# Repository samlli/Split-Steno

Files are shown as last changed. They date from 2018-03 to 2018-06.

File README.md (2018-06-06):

# Split Stenographic Keyboard

**current working version: rev1.1**

Open source PCB design for a mirrored keyboard with the layout below:

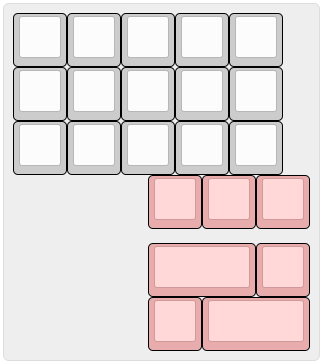
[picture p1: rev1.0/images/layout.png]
layout


**rev1.x Features:**

ATmega32u4 controller  
Mirrored Alps + MX compat  
3 x 1u / 2u + 1u bottom row layout support  
THT & SMD support  
<100x100mm square PCB size  
QMK firmware

**rev2.x Features:**

ATxmega controller  
nRF24L01+ wireless  
Per-key LED backlighting  
WS2812b underglow   
Wired & coin cell battery support  
Trackpoint support  
KeyPlus firmware

**rev3.x Features:**
Minimized PCB layout
Removed mirrored compat

## Build Guide

**required parts**

Quantities are for a single PCB, double required quantities if you build two halves!

- 1x Atxmega32a4u
- 17-18x MX / Alps switches
- 0-1x PCB mount stabilizer
- 1x PJ-320A TRRS jack
- 1x Hirose 5S8 USB Mini B
- 1x Fuse
- 4x 0.1uF Capacitors
- 1x 10uF Capacitor
- 2x 4.7k Resistor
- 1x Voltage Regulator (component name needed)

## Setup

Fancy K+ stuff goes here I guess

## Why?

**why is this keyboard a thing?**

Good question - I'm not quite sure to be honest... when you find out, let me know please

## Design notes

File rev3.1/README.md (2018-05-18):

# rev3.0

**Features:**

Integrated ATxmega controller  
SMD only  
No Diodes   
Wireless NRF

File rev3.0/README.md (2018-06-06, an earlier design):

# rev3.0

**Features:**

Minimized PCB footprint  
Lite version with core functionality only  
NRF and RGB moved to breakouts  
Routed GND with 0 vias

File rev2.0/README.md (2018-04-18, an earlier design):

# rev2.0

**WARNING: INCOMPLETE/ABANDONED**

Reason: big forehead, decided to scrap and proceed with 2.1

**Features:**

Integrated ATxmega controller  
SMD only  
No Diodes  
Reversible PCB

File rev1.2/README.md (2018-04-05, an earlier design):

# rev1.2

**WARNING: INCOMPLETE/ABANDONED**

**Features:**

Added LED backlighting

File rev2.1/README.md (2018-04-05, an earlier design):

# rev2.1

**Features:**

Integrated ATxmega controller  
SMD only  
No Diodes  
Reversible PCB  
Wireless NRF

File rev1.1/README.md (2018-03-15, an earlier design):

# rev1.1

**left half**

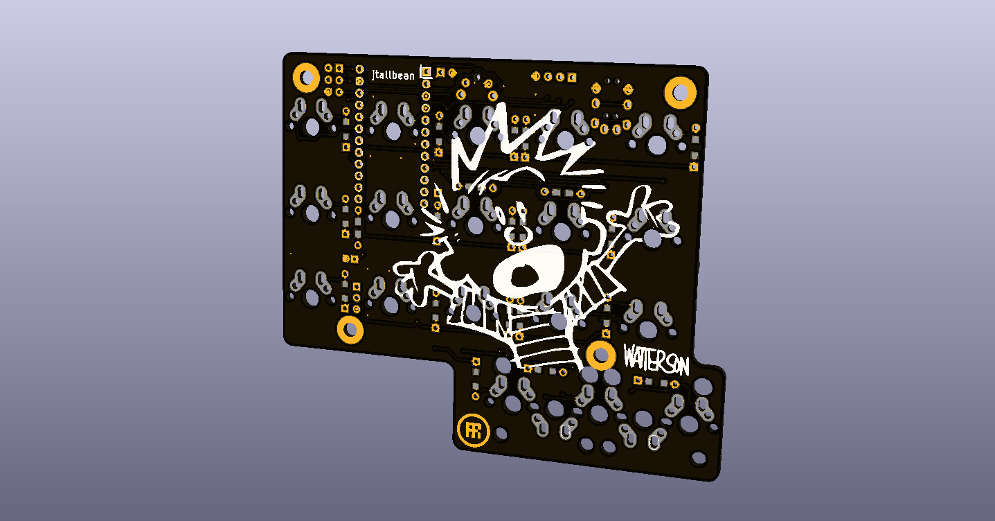
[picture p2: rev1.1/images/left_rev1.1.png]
left half


**right half**

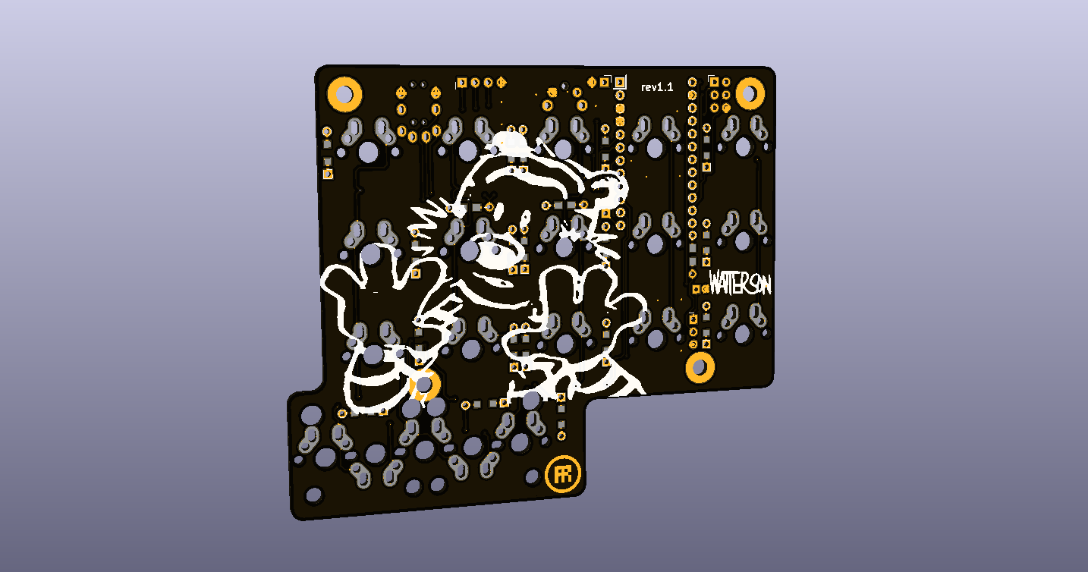
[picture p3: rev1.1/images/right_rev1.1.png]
right half


**Features:**

Pro Micro only  
Added mounting holes  
Added breakout for unused pins  
THT + SMD  
Added silkscreen design  
Cleaner routing

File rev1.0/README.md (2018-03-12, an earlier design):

# rev1.0

**left half**

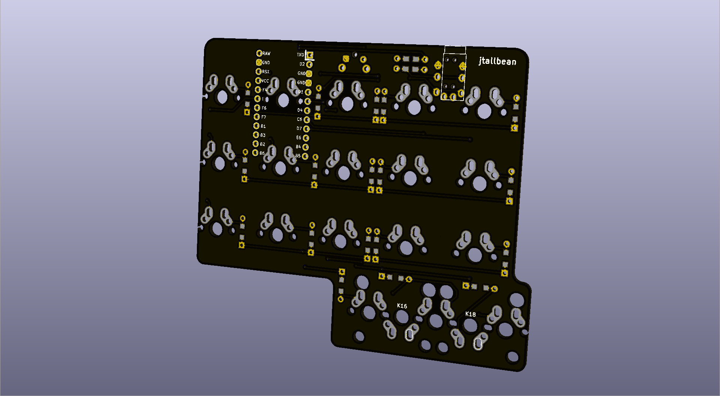
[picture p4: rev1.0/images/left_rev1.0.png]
left half


**right half**

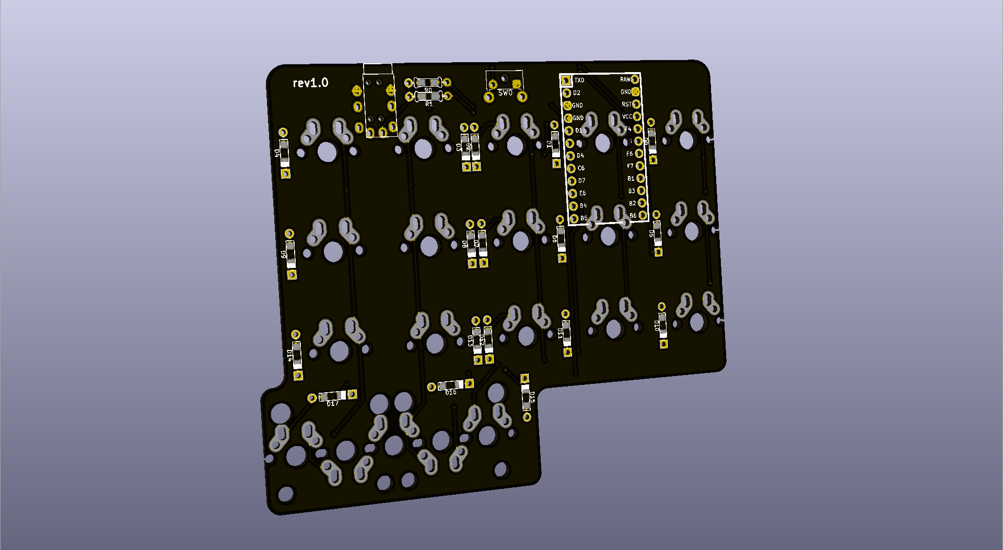
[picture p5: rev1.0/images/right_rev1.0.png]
right half


**Features:**

Pro Micro only  
NO mounting holes  
NO breakout for unused pins  
NO silkscreen design aside from name/rev  
First KiCad design - routing etc. not the cleanest

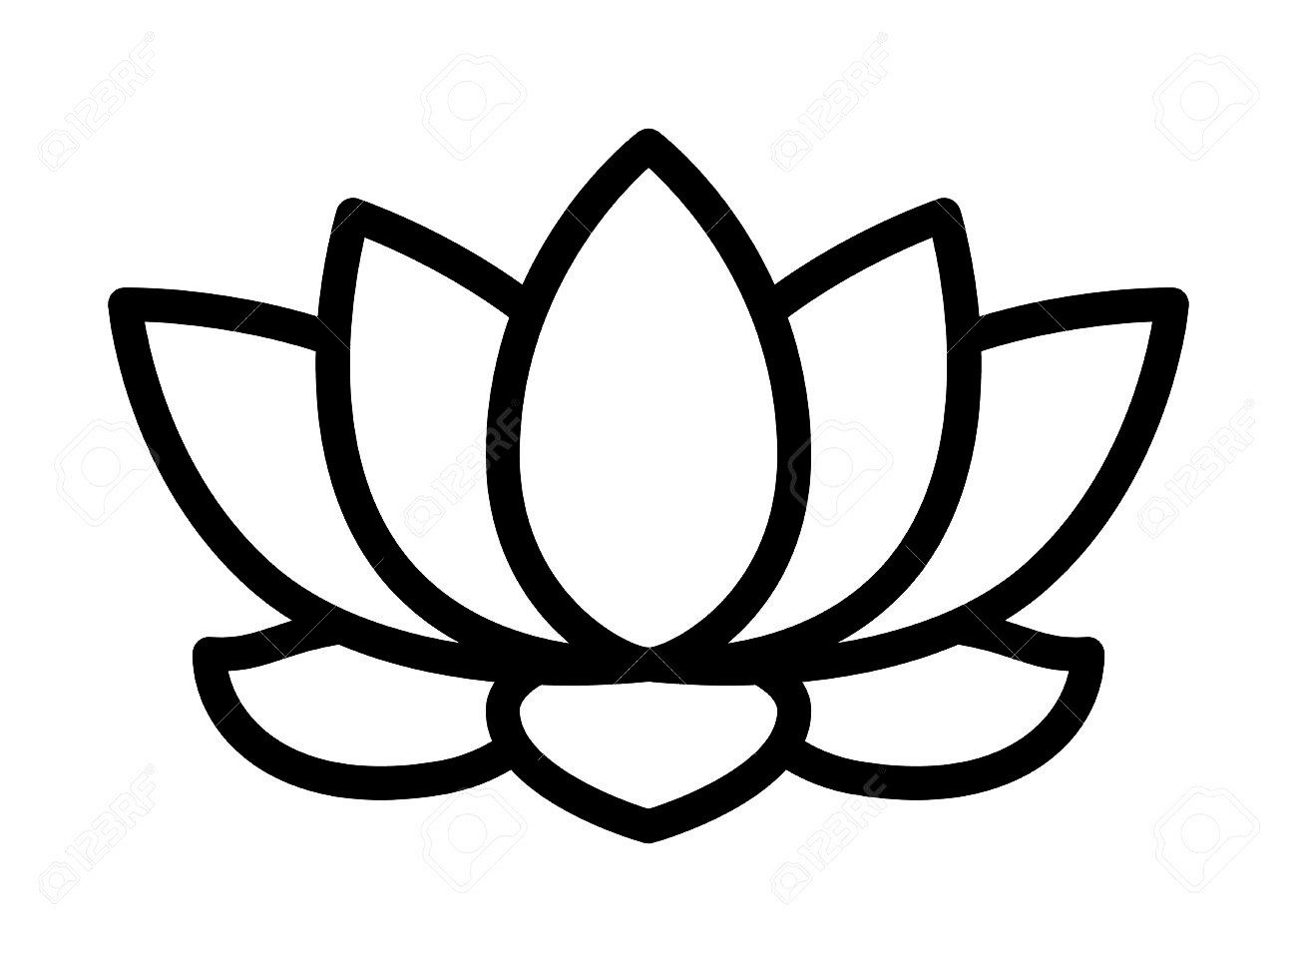
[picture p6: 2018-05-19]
rev3.1/images/lotus.png

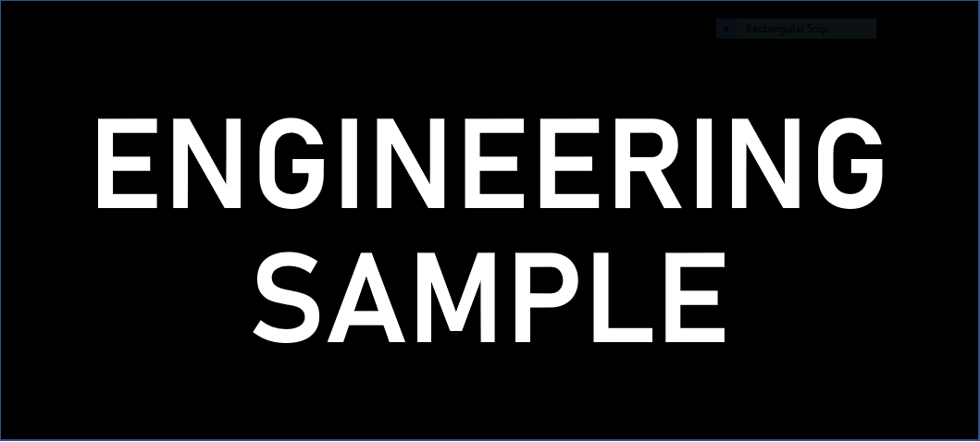
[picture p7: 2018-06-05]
rev3.1/images/engineering_sample.PNG

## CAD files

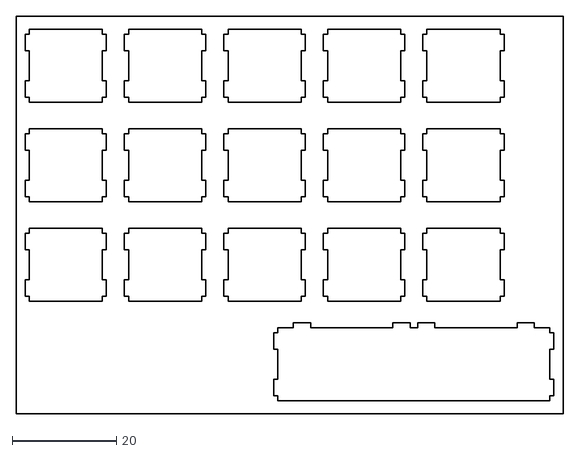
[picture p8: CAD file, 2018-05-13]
plate/split_steno_plate_universal_ch.dxf
104.8 x 76.2

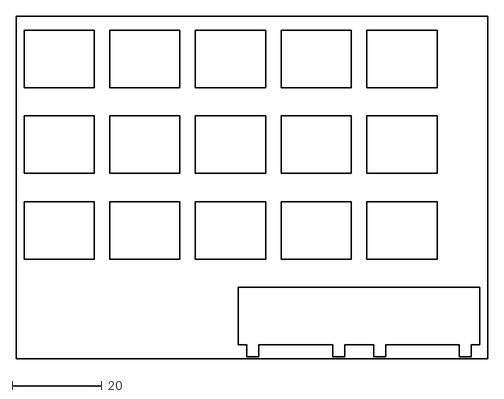
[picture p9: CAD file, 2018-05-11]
plate/split_steno_plate_universal_alps.dxf
104.8 x 76.2

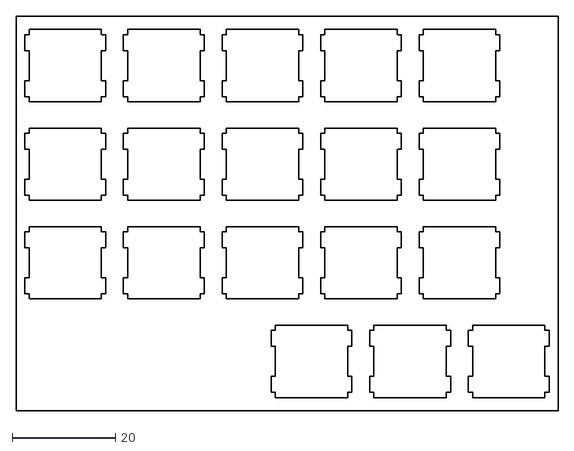
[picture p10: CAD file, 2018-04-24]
plate/split_steno_plate_1u_ch.dxf
104.8 x 76.2

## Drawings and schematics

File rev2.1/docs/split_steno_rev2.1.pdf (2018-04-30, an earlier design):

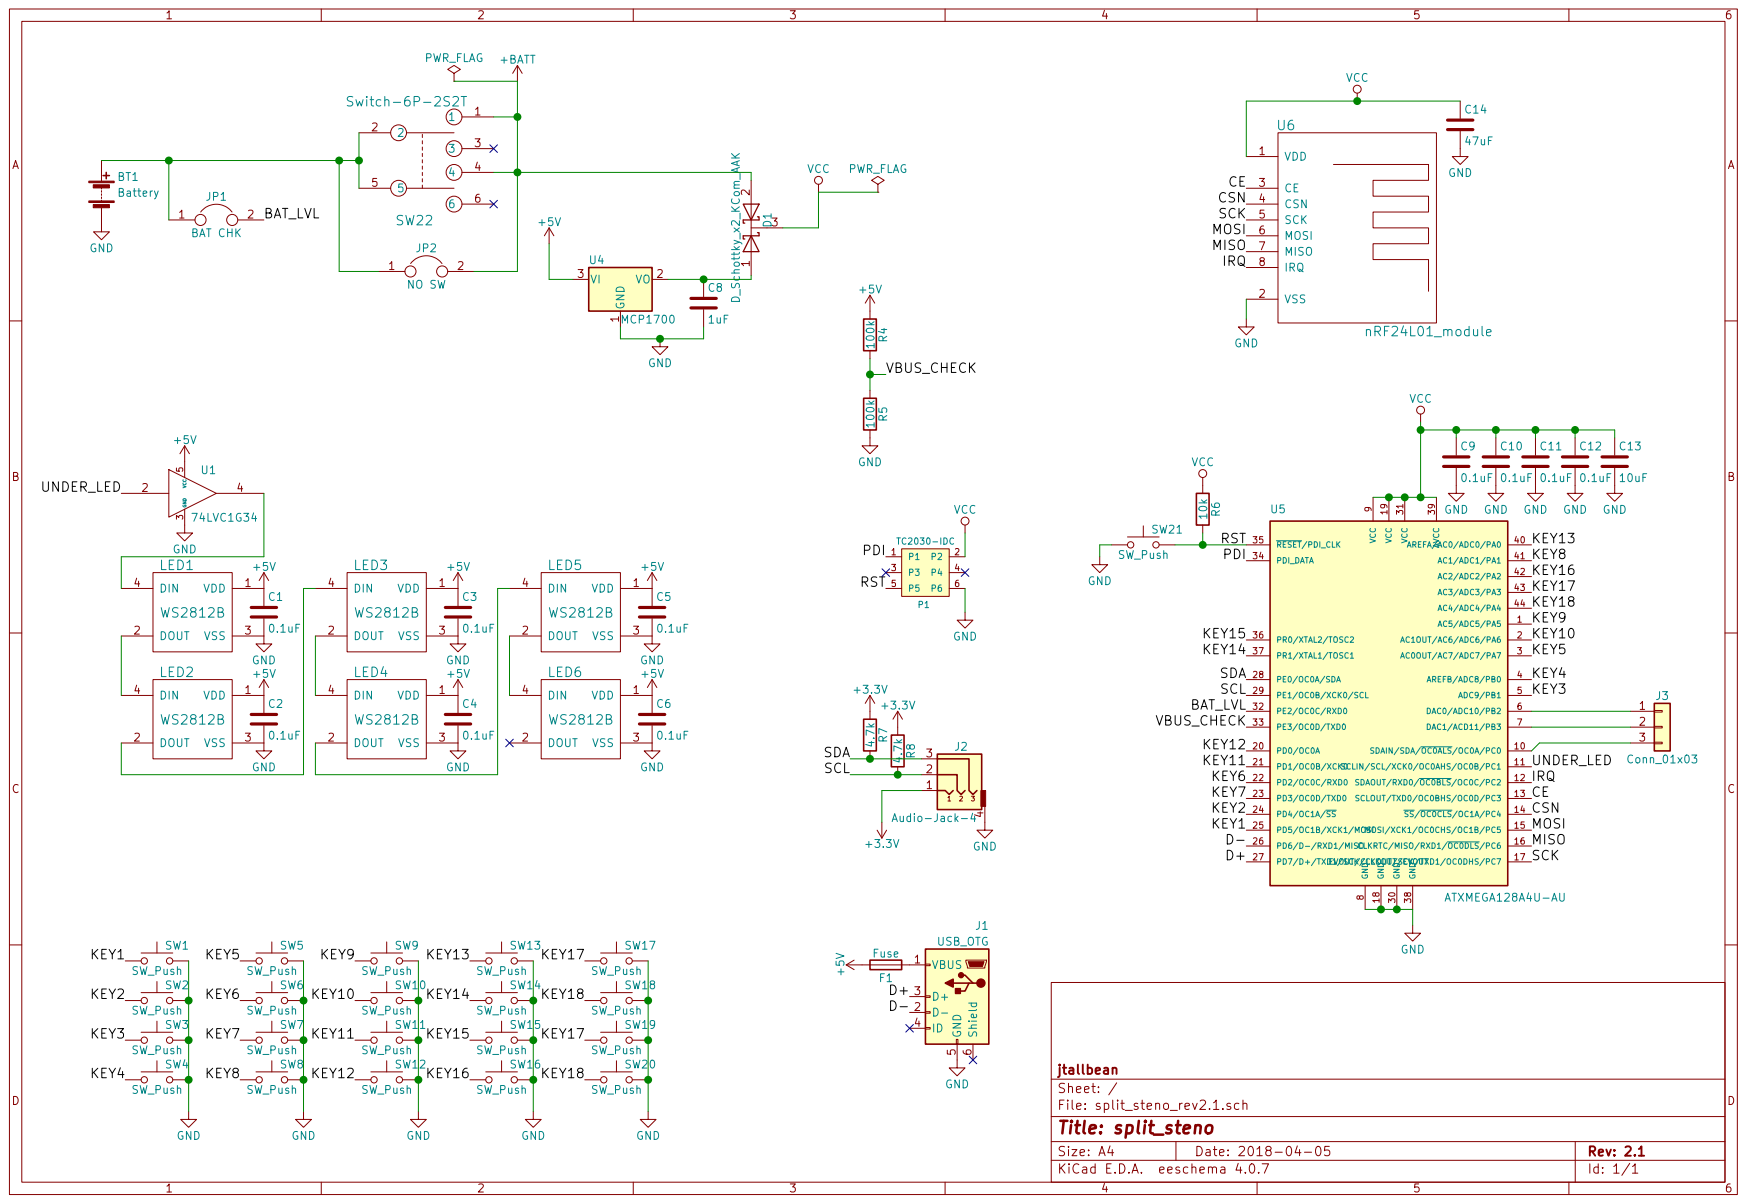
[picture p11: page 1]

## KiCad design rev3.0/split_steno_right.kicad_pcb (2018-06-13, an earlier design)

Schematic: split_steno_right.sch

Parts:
C1: 10uF; C_0603_HandSoldering
C2, C3, C4, C5: 0.1uF; C_0603_HandSoldering
F1: Fuse; Fuse_SMD1206_HandSoldering
J1: USB_B; USB_miniB_hirose_5S8
J2: Audio-Jack-4; TRRS-PJ-320A
J3, J5: Conn_02x04_Odd_Even; Pin_Header_Straight_2x04_Pitch2.54mm
J4: Conn_01x02; Pin_Header_Straight_1x02_Pitch2.54mm
P1: TC2030-IDC; TC2030-NL_SMALL_AND_IDC_PDI
R1, R2: 4.7k; R_0603_HandSoldering
SW1, SW2, SW3, SW4, SW5, SW6, SW7, SW8, SW9, SW10, SW11, SW12, SW13, SW14, SW15, SW16, SW17, SW18: SW_Push; MX-1U-NoLED
SW19, SW20: SW_Push; MX-2U-NoLED
U1: MIC550X; SOT-23-5_HandSoldering
U2: ATXMEGA-A4U-EPAD; TQFP-44_10x10mm_Pitch0.8mm

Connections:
+5V: F1.1, U1.1 (VIN), U1.3 (EN)
/CE: J3.3, U2.12 (SDAOUT/RXD0/~OC0BLS~/OC0C/PC2)
/CSN: J3.4, U2.14 (~SS~/~OC0CLS~/OC1A/PC4)
/D+: J1.3 (D+), U2.27 (PD7/D+/TXD1/SCK)
/D-: J1.2 (D-), U2.26 (PD6/D-/RXD1/MISO)
/EXTRA1: J4.1, U2.37 (PR1/XTAL1/TOSC1)
/EXTRA2: J5.4, U2.40 (AREFA/AC0/ADC0/PA0)
/EXTRA3: J5.3, U2.41 (AC1/ADC1/PA1)
/EXTRA4: J5.6, U2.42 (AC2/ADC2/PA2)
/EXTRA5: J5.5, U2.43 (AC3/ADC3/PA3)
/EXTRA6: J5.8, U2.44 (AC4/ADC4/PA4)
/IRQ: J3.8, U2.13 (SCLOUT/TXD0/OC0BHS/OC0D/PC3)
/KEY1: SW1.1, U2.36 (PR0/XTAL2/TOSC2)
/KEY2: SW2.1, U2.33 (PE3/OC0D/TXD0)
/KEY3: SW3.1, U2.25 (PD5/OC1B/XCK1/MOSI)
/KEY4: SW4.1, U2.24 (PD4/OC1A/~SS~)
/KEY5: SW5.1, U2.22 (PD2/OC0C/RXD0)
/KEY6: SW6.1, U2.2 (AC1OUT/AC6/ADC6/PA6)
/KEY7: SW7.1, U2.32 (PE2/OC0C/RXD0)
/KEY8: SW8.1, U2.20 (PD0/OC0A)
/KEY9: SW9.1, U2.23 (PD3/OC0D/TXD0)
/KEY10: SW10.1, U2.21 (PD1/OC0B/XCK0)
/KEY11: SW11.1, U2.1 (AC5/ADC5/PA5)
/KEY12: SW12.1, U2.3 (AC0OUT/AC7/ADC7/PA7)
/KEY13: SW13.1, U2.6 (DAC0/ADC10/PB2)
/KEY14: SW14.1, U2.10 (SDAIN/SDA/~OC0ALS~/OC0A/PC0)
/KEY15: SW15.1, U2.11 (SCLIN/SCL/XCK0/OC0AHS/OC0B/PC1)
/KEY16: SW16.1, SW19.1, U2.4 (AREFB/ADC8/PB0)
/KEY17: SW17.1, SW20.1, U2.5 (ADC9/PB1)
/KEY18: SW18.1, U2.7 (DAC1/ACD11/PB3)
/MISO: J3.7, U2.16 (CLKRTC/MISO/RXD1/~OC0DLS~/PC6)
/MOSI: J3.6, U2.15 (MOSI/XCK1/OC0CHS/OC1B/PC5)
/PDI: P1.1, U2.34 (PDI_DATA)
/RST: P1.5, U2.35 (~RESET~/PDI_CLK)
/SCK: J3.5, U2.17 (CLKOUT/SCK/TXD1/OC0DHS/PC7)
/SCL: J2.2, R1.1, U2.29 (PE1/OC0B/XCK0/SCL)
/SDA: J2.3, R2.1, U2.28 (PE0/OC0A/SDA)
GND: C1.2, C2.2, C3.2, C4.2, C5.2, J1.4 (GND), J1.5 (Shield), J1.6, J2.4, J3.1, J4.2, J5.1, P1.6, SW1.2, SW2.2, SW3.2, SW4.2, SW5.2, SW6.2, SW7.2, SW8.2, SW9.2, SW10.2, SW11.2, SW12.2, SW13.2, SW14.2, SW15.2, SW16.2, SW17.2, SW18.2, SW19.2, SW20.2, U1.2 (GND), U2.8 (GND), U2.18 (GND), U2.30 (GND), U2.38 (GND), U2.45 (EPAD)
unnamed: F1.2, J1.1 (VBUS)
VCC: C1.1, C2.1, C3.1, C4.1, C5.1, J2.1, J3.2, J5.2, P1.2, R1.2, R2.2, U1.5 (VOUT), U2.9 (VCC), U2.19 (VCC), U2.31 (VCC), U2.39 (AVCC)

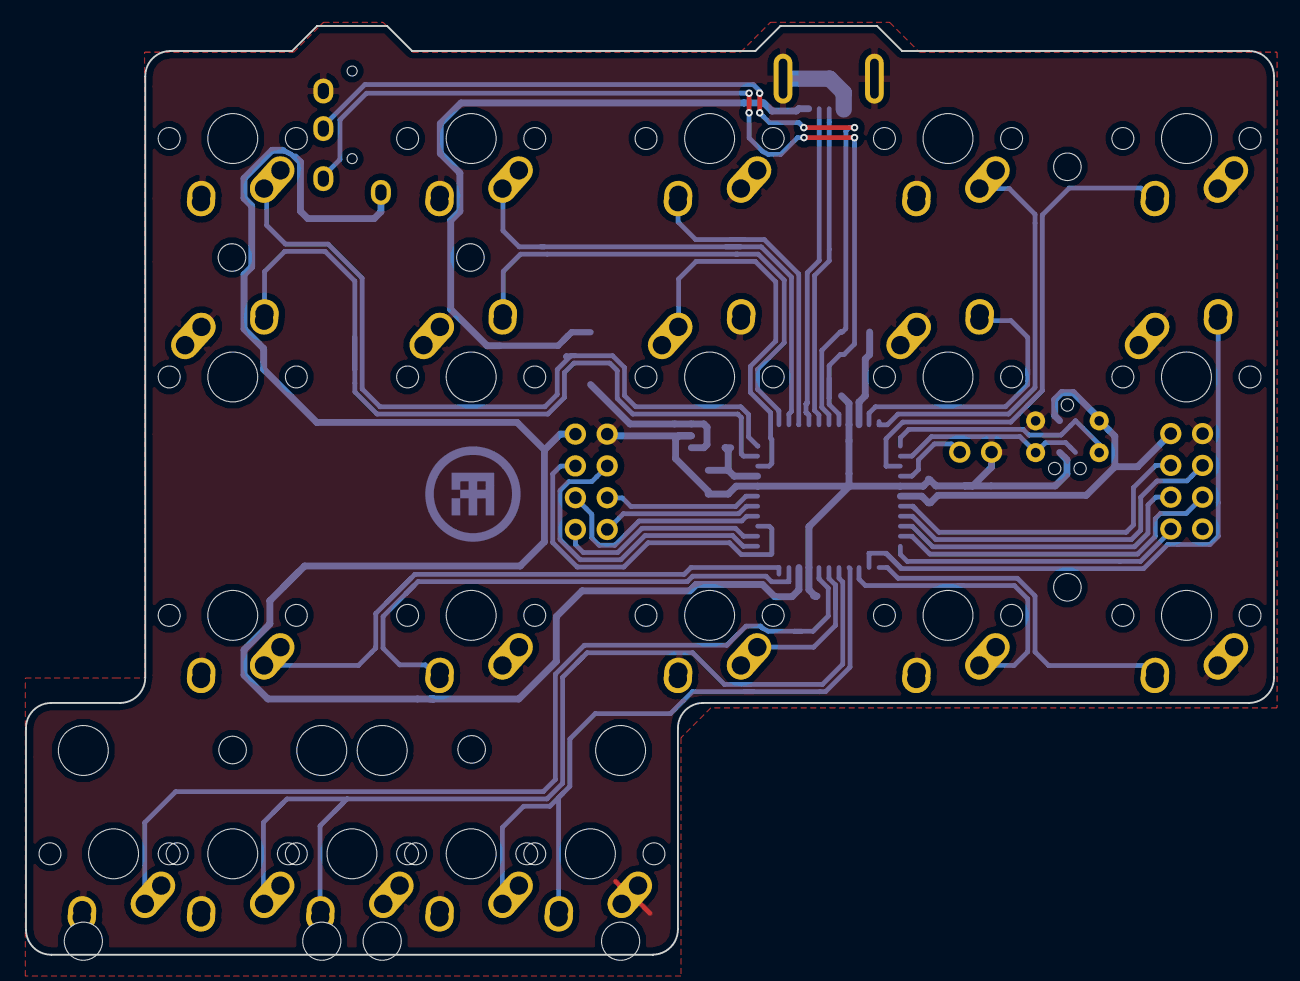
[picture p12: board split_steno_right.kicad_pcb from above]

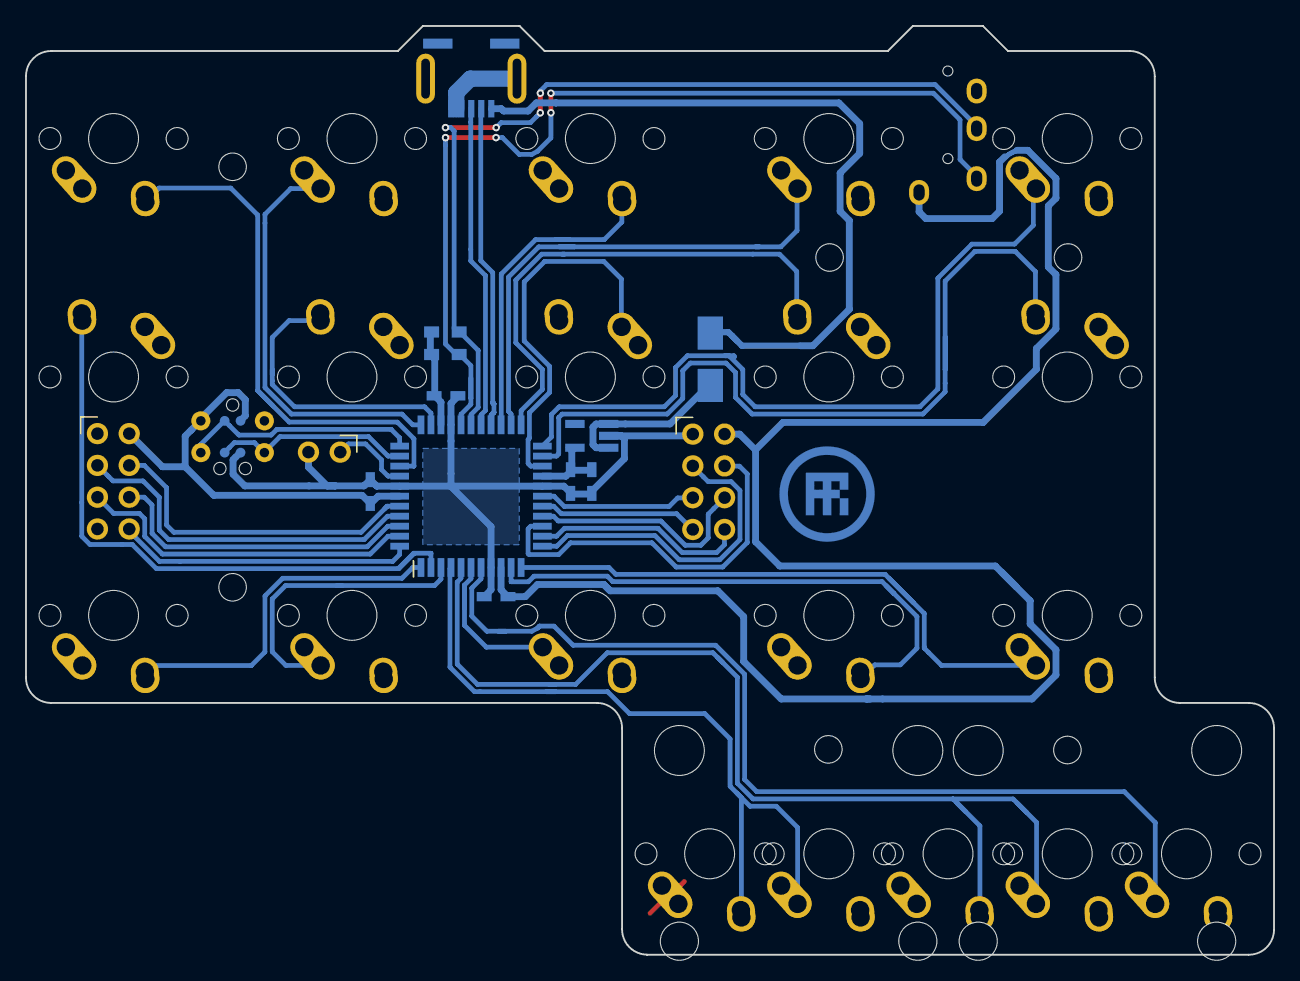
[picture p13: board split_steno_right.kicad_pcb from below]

Board: 2 copper layers, 99.7 x 74.2 mm, 42 parts (16 on the bottom side), 40 nets.

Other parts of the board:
M2, M2#2, M2#3, M2#4, M2#5, M2#6: MountingHole_2.2mm_M2

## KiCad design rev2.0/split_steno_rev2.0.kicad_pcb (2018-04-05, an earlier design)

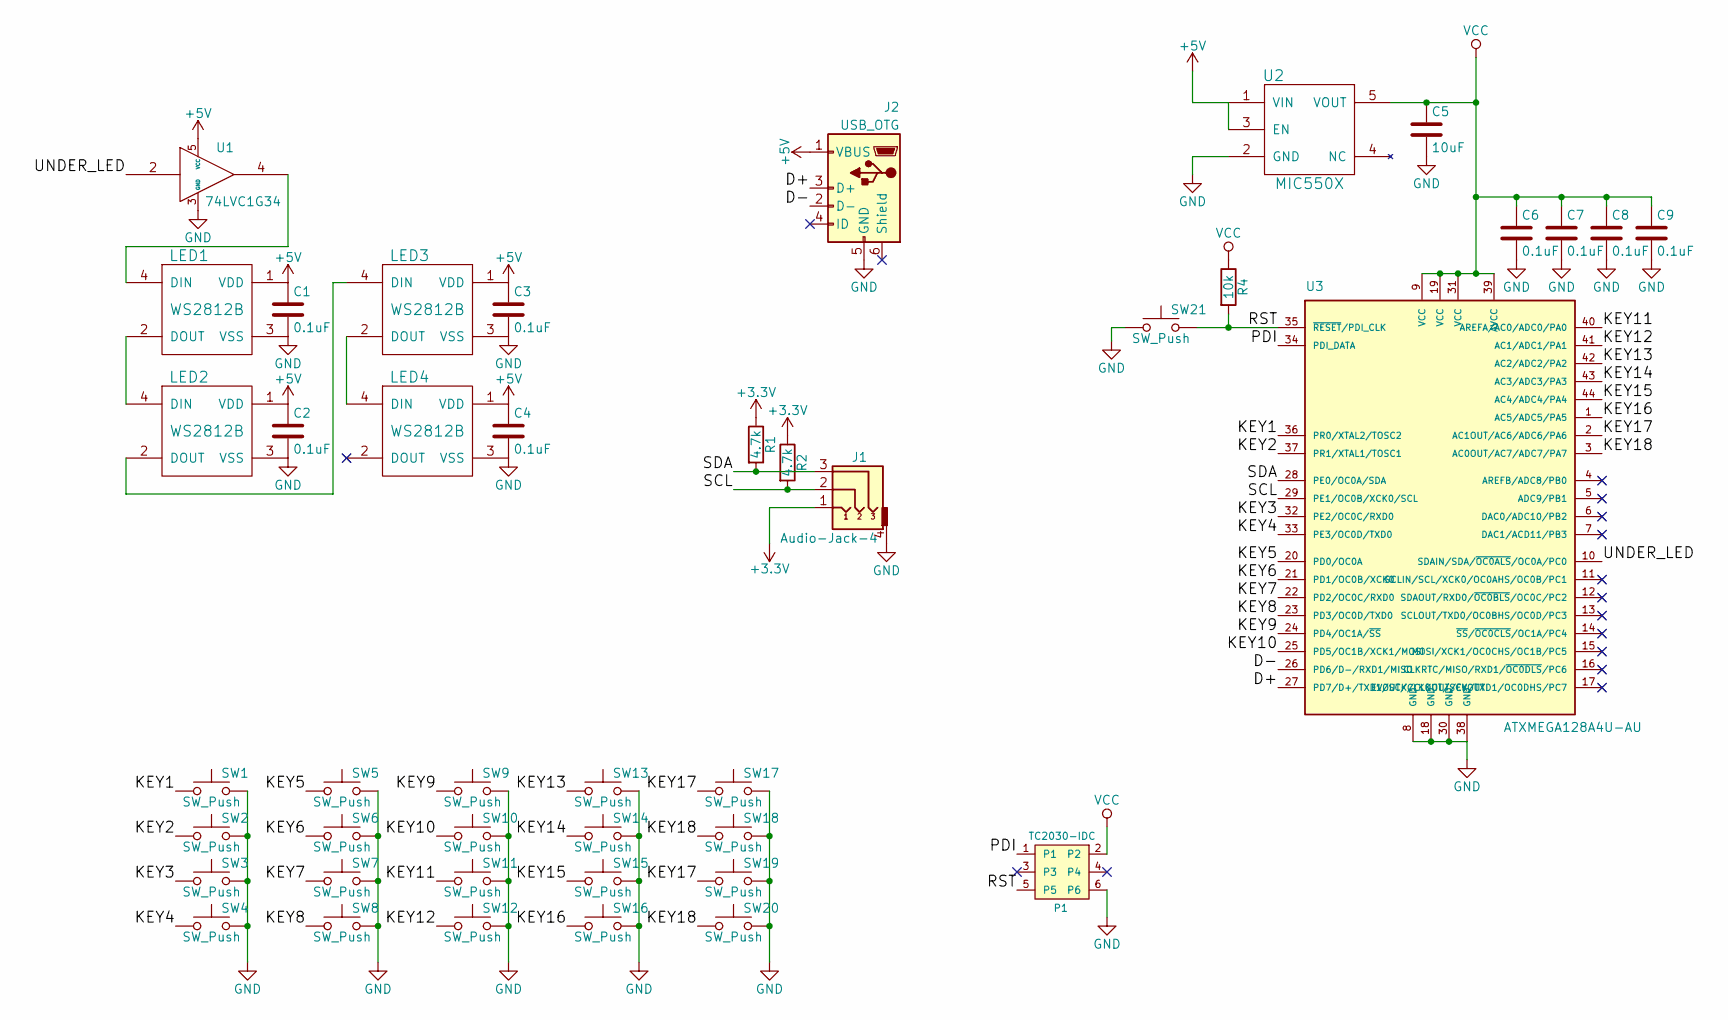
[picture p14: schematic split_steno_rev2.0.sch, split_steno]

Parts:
C1, C2, C3, C4, C6, C7, C8, C9: 0.1uF; C_0603_HandSoldering
C5: 10uF; C_0603_HandSoldering
J1: Audio-Jack-4; TRRS-PJ-320A
J2: USB_OTG; USB_miniB
LED1, LED2, LED3, LED4: WS2812B
P1: TC2030-IDC; Tag-Connect_TC2030-IDC-NL
R1, R2: 4.7k; R_0603_HandSoldering
R4: 10k; R_0603_HandSoldering
SW1, SW2, SW3, SW4, SW5, SW6, SW7, SW8, SW9, SW10, SW11, SW12, SW13, SW14, SW15, SW16, SW17, SW18: SW_Push; Hybrid_PCB_100H_Dual_hole
SW19, SW20: SW_Push; Hybrid_PCB_200H-dual-nosilk
SW21: SW_Push; SwitchPush_C&K_MultiFoot_RS-187R05A2-DS_And_PTS645_SMT
U1: 74LVC1G34; SOT-353_SC-70-5_Handsoldering
U2: MIC550X; SOT-23-5_HandSoldering
U3: ATXMEGA128A4U-AU; TQFP-44_10x10mm_Pitch0.8mm

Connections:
+3V3: J1.1, R1.1, R2.1
+5V: C1.1, C2.1, C3.1, C4.1, J2.1 (VBUS), LED1.1 (VDD), LED2.1 (VDD), LED3.1 (VDD), LED4.1 (VDD), U1.5 (VCC), U2.1 (VIN), U2.3 (EN)
/D+: J2.3 (D+), U3.27 (PD7/D+/TXD1/SCK/CLKOUT/EVOUT)
/D-: J2.2 (D-), U3.26 (PD6/D-/RXD1/MISO)
/KEY1: SW1.1, U3.36 (PR0/XTAL2/TOSC2)
/KEY2: SW2.1, U3.37 (PR1/XTAL1/TOSC1)
/KEY3: SW3.1, U3.32 (PE2/OC0C/RXD0)
/KEY4: SW4.1, U3.33 (PE3/OC0D/TXD0)
/KEY5: SW5.1, U3.20 (PD0/OC0A)
/KEY6: SW6.1, U3.21 (PD1/OC0B/XCK0)
/KEY7: SW7.1, U3.22 (PD2/OC0C/RXD0)
/KEY8: SW8.1, U3.23 (PD3/OC0D/TXD0)
/KEY9: SW9.1, U3.24 (PD4/OC1A/~SS~)
/KEY10: SW10.1, U3.25 (PD5/OC1B/XCK1/MOSI)
/KEY11: SW11.1, U3.40 (AREFA/AC0/ADC0/PA0)
/KEY12: SW12.1, U3.41 (AC1/ADC1/PA1)
/KEY13: SW13.1, U3.42 (AC2/ADC2/PA2)
/KEY14: SW14.1, U3.43 (AC3/ADC3/PA3)
/KEY15: SW15.1, U3.44 (AC4/ADC4/PA4)
/KEY16: SW16.1, U3.1 (AC5/ADC5/PA5)
/KEY17: SW17.1, SW19.1, U3.2 (AC1OUT/AC6/ADC6/PA6)
/KEY18: SW18.1, SW20.1, U3.3 (AC0OUT/AC7/ADC7/PA7)
/PDI: P1.1, U3.34 (PDI_DATA)
/RST: P1.5, R4.2, SW21.2, U3.35 (~RESET~/PDI_CLK)
/SCL: J1.2, R2.2, U3.29 (PE1/OC0B/XCK0/SCL)
/SDA: J1.3, R1.2, U3.28 (PE0/OC0A/SDA)
/UNDER_LED: U1.2, U3.10 (SDAIN/SDA/~OC0ALS~/OC0A/PC0)
GND: C1.2, C2.2, C3.2, C4.2, C5.2, C6.2, C7.2, C8.2, C9.2, J1.4, J2.5 (GND), LED1.3 (VSS), LED2.3 (VSS), LED3.3 (VSS), LED4.3 (VSS), P1.6, SW1.2, SW2.2, SW3.2, SW4.2, SW5.2, SW6.2, SW7.2, SW8.2, SW9.2, SW10.2, SW11.2, SW12.2, SW13.2, SW14.2, SW15.2, SW16.2, SW17.2, SW18.2, SW19.2, SW20.2, SW21.1, U1.3 (GND), U2.2 (GND), U3.8 (GND), U3.18 (GND), U3.30 (GND), U3.38 (GND)
unnamed: LED1.2 (DOUT), LED2.4 (DIN)
unnamed: LED1.4 (DIN), U1.4
unnamed: LED2.2 (DOUT), LED3.4 (DIN)
unnamed: LED3.2 (DOUT), LED4.4 (DIN)
VCC: C5.1, C6.1, C7.1, C8.1, C9.1, P1.2, R4.1, U2.5 (VOUT), U3.9 (VCC), U3.19 (VCC), U3.31 (VCC), U3.39 (AVCC)

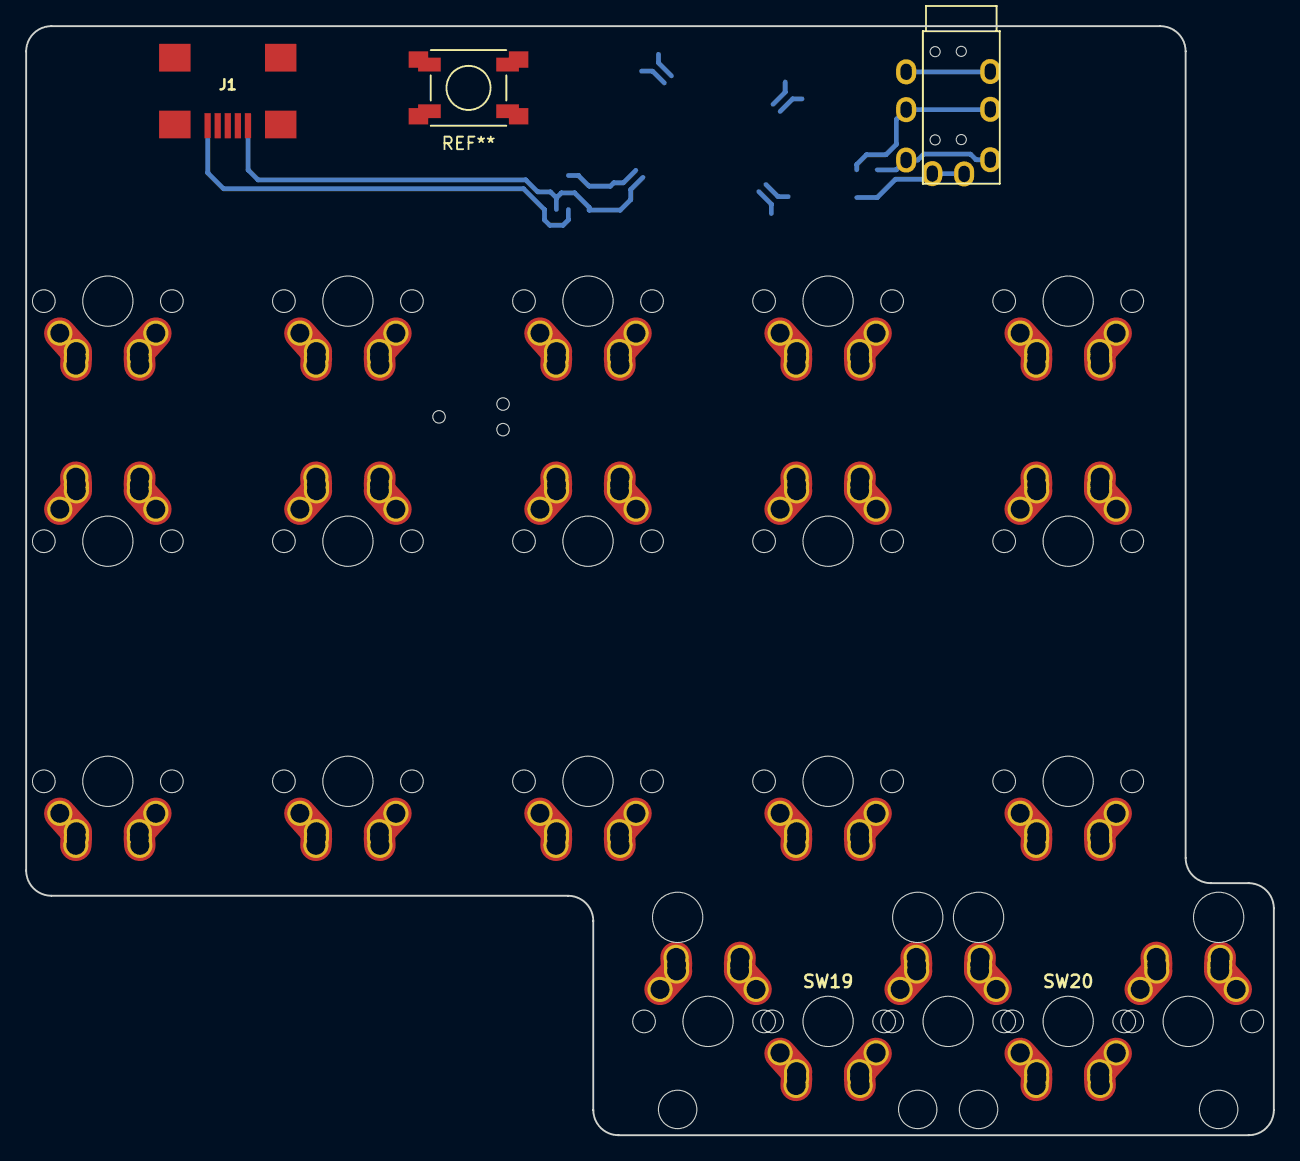
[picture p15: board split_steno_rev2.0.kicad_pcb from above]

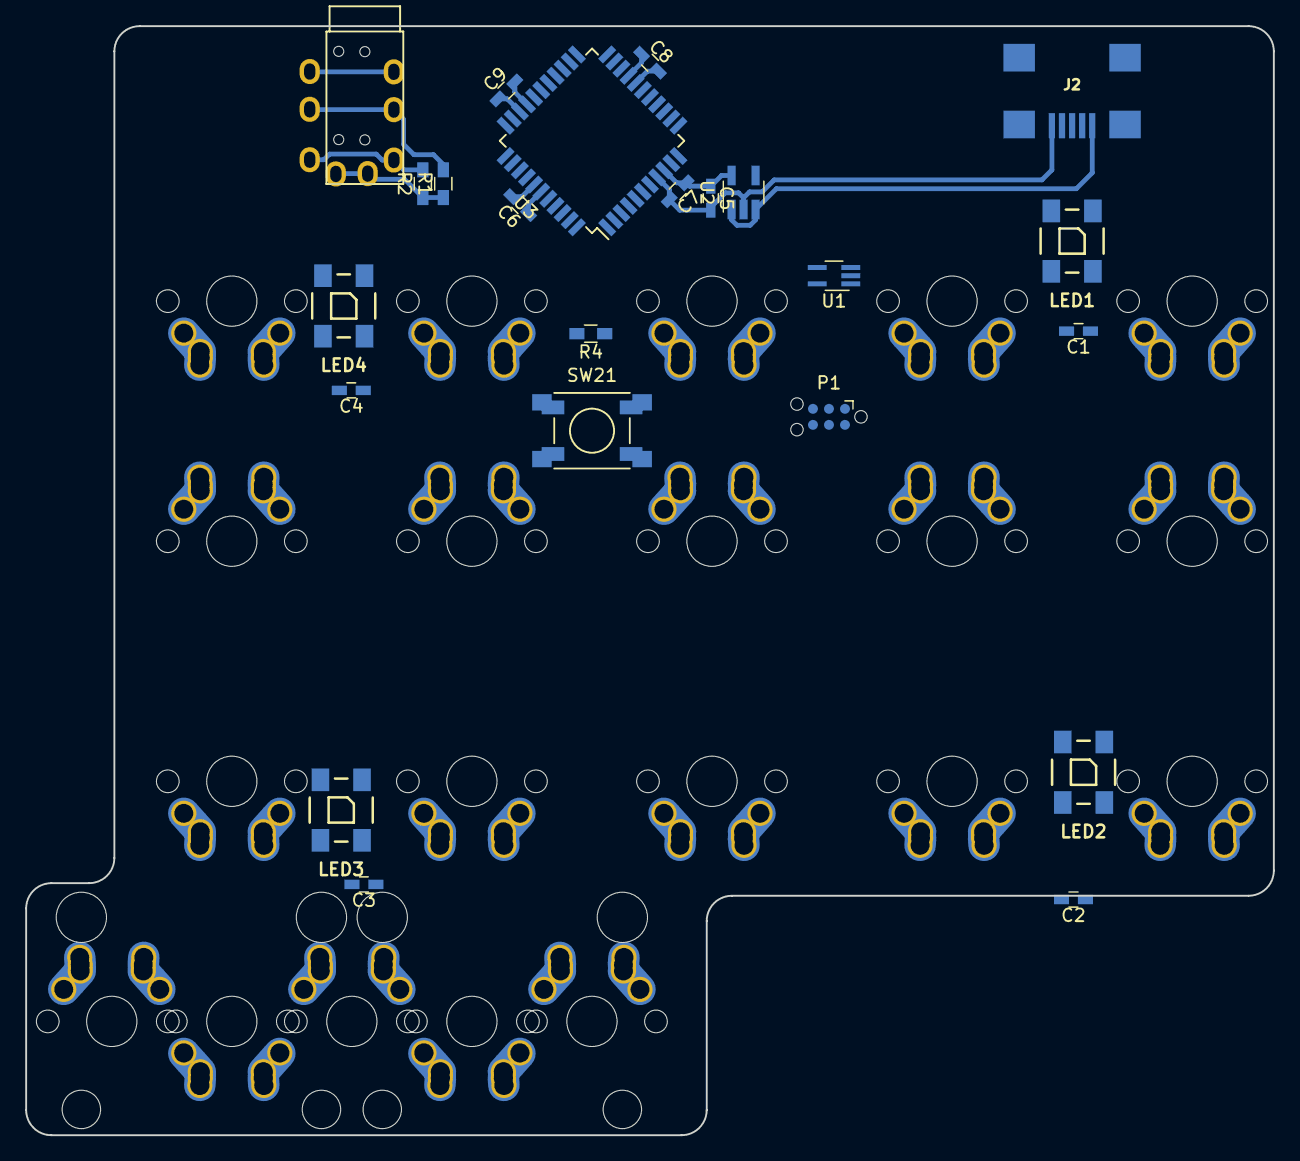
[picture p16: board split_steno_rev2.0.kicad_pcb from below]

Board: 2 copper layers, 99.0 x 88.0 mm, 44 parts (22 on the bottom side), 33 nets.

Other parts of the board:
J1#2: USB_B; USB_miniB

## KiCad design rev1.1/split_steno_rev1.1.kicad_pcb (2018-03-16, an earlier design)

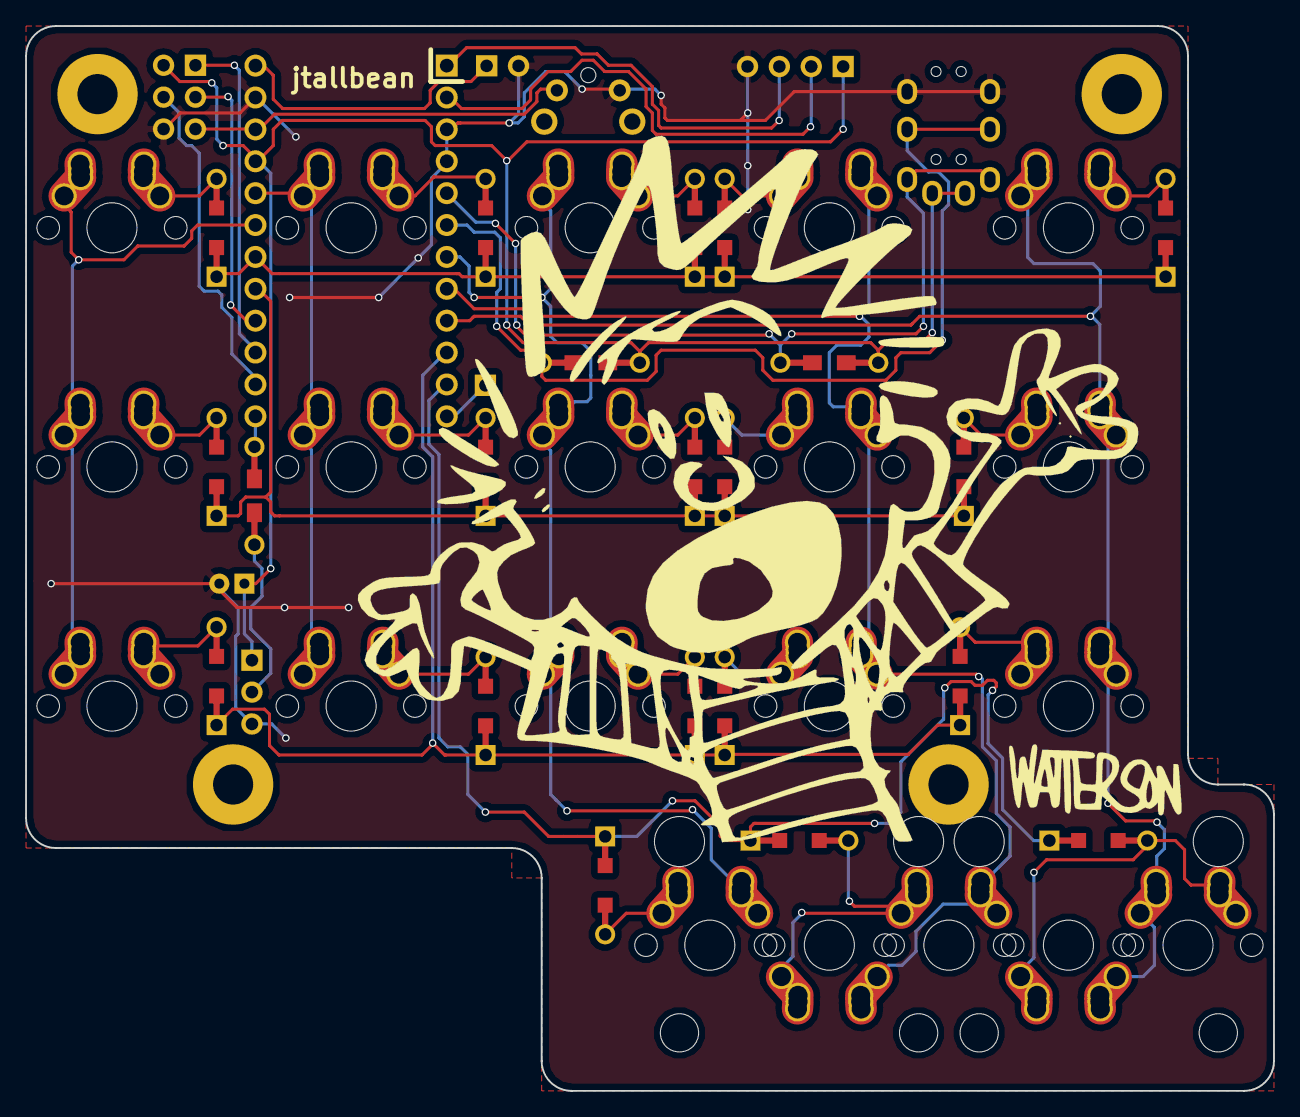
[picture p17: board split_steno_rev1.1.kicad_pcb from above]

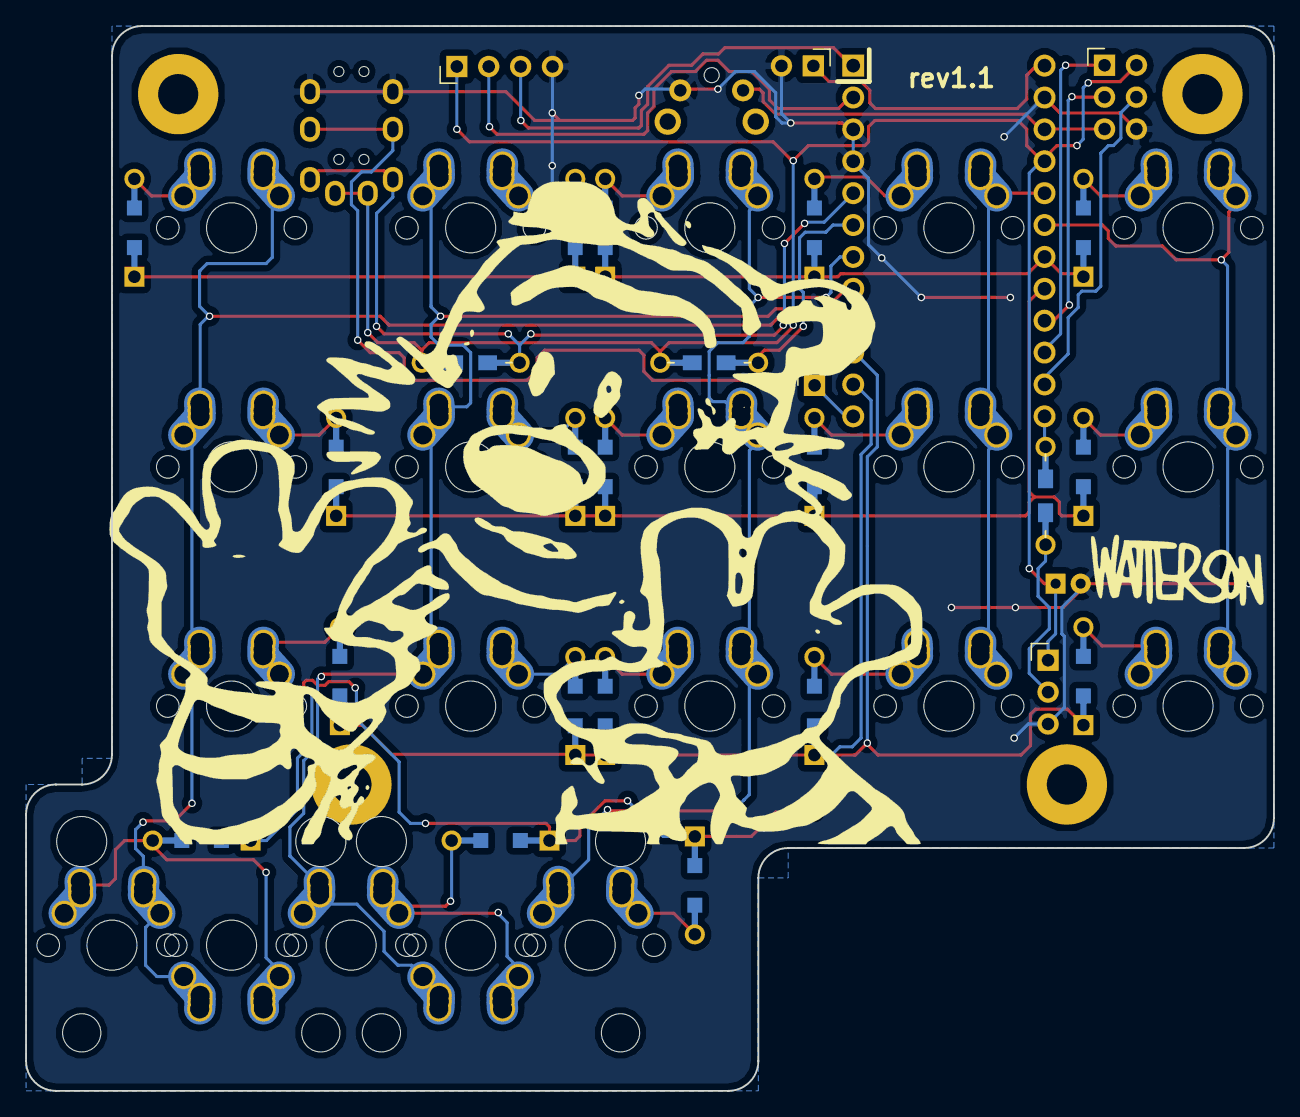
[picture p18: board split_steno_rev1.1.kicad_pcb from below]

Board: 2 copper layers, 99.4 x 84.8 mm, 50 parts (30 on the bottom side), 41 nets.

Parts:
C1: 100; CP_Radial_D5.0mm_P2.00mm
D1, D2, D3, D4, D5, D6, D7, D8, D9, D10, D11, D12, D13, D14, D15, D16, D17, D18: D; Diode-dual
J1: i2c; TRRS-PJ-320A
J2: serial; Pin_Header_Straight_1x04_Pitch2.54mm
J3: rgb; Pin_Header_Straight_1x03_Pitch2.54mm
J4: icsp; Pin_Header_Straight_2x03_Pitch2.54mm
J5: raw; Pin_Header_Straight_1x02_Pitch2.54mm
J6: extra; Pin_Header_Straight_1x01_Pitch2.54mm
K1, K2, K3, K5, K6, K7, K8, K11, K12, K13, K18: KEYSW; Hybrid_PCB_100H_Dual_hole
K4, K9, K10, K14, K15, K16, K17: KEYSW; Hybrid_PCB_100H_Dual_hole-flip
K19, K20: KEYSW; Hybrid_PCB_200H-dual-nosilk
R1, R2: 4.7k; Resistor-Hybrid
R3: 470; Resistor-Hybrid
SW1: reset; SW_Tactile_SPST_Angled_MJTP1117
U1: ProMicro; ArduinoProMicro

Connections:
+6V: J5.1, U1.24
/c1: K1.1, K6.1, K11.1, U1.19
/c2: K2.1, K7.1, K12.1, U1.20
/c3: K3.1, K8.1, K13.1, K16.1, U1.7
/c4: K4.1, K9.1, K14.1, K17.1, K19.1, U1.8
/c5: K5.1, K10.1, K15.1, K18.1, K20.1, U1.9
/d1: J1.2, R1.1, U1.5
/d2: J1.3, R2.1, U1.6
/d3: J6.1, U1.12
/d4: R3.2, U1.13
/miso: J4.1, U1.15
/mosi: J4.4, U1.14
/r1: D1.1, D2.1, D3.1, D4.1, D5.1, U1.18
/r2: D6.1, D7.1, D8.1, D9.1, D10.1, U1.17
/r3: D11.1, D12.1, D13.1, D14.1, D15.1, U1.10
/r4: D16.1, D17.1, D18.1, U1.11
/rst: J4.5, SW1.2, U1.22
/rx: J2.2, U1.2
/sclk: J4.3, U1.16
/tx: J2.3, U1.1
GND: C1.2, J1.4, J2.4, J3.3, J4.6, J5.2, SW1.1, U1.3, U1.4, U1.23
unnamed: D1.2, K1.2
unnamed: D2.2, K2.2
unnamed: D3.2, K3.2
unnamed: D4.2, K4.2
unnamed: D5.2, K5.2
unnamed: D6.2, K6.2
unnamed: D7.2, K7.2
unnamed: D8.2, K8.2
unnamed: D9.2, K9.2
unnamed: D10.2, K10.2
unnamed: D11.2, K11.2
unnamed: D12.2, K12.2
unnamed: D13.2, K13.2
unnamed: D14.2, K14.2
unnamed: D15.2, K15.2
unnamed: D16.2, K16.2
unnamed: D17.2, K17.2, K19.2
unnamed: D18.2, K18.2, K20.2
unnamed: J3.2, R3.1
VCC: C1.1, J1.1, J2.1, J3.1, J4.2, R1.2, R2.2, U1.21

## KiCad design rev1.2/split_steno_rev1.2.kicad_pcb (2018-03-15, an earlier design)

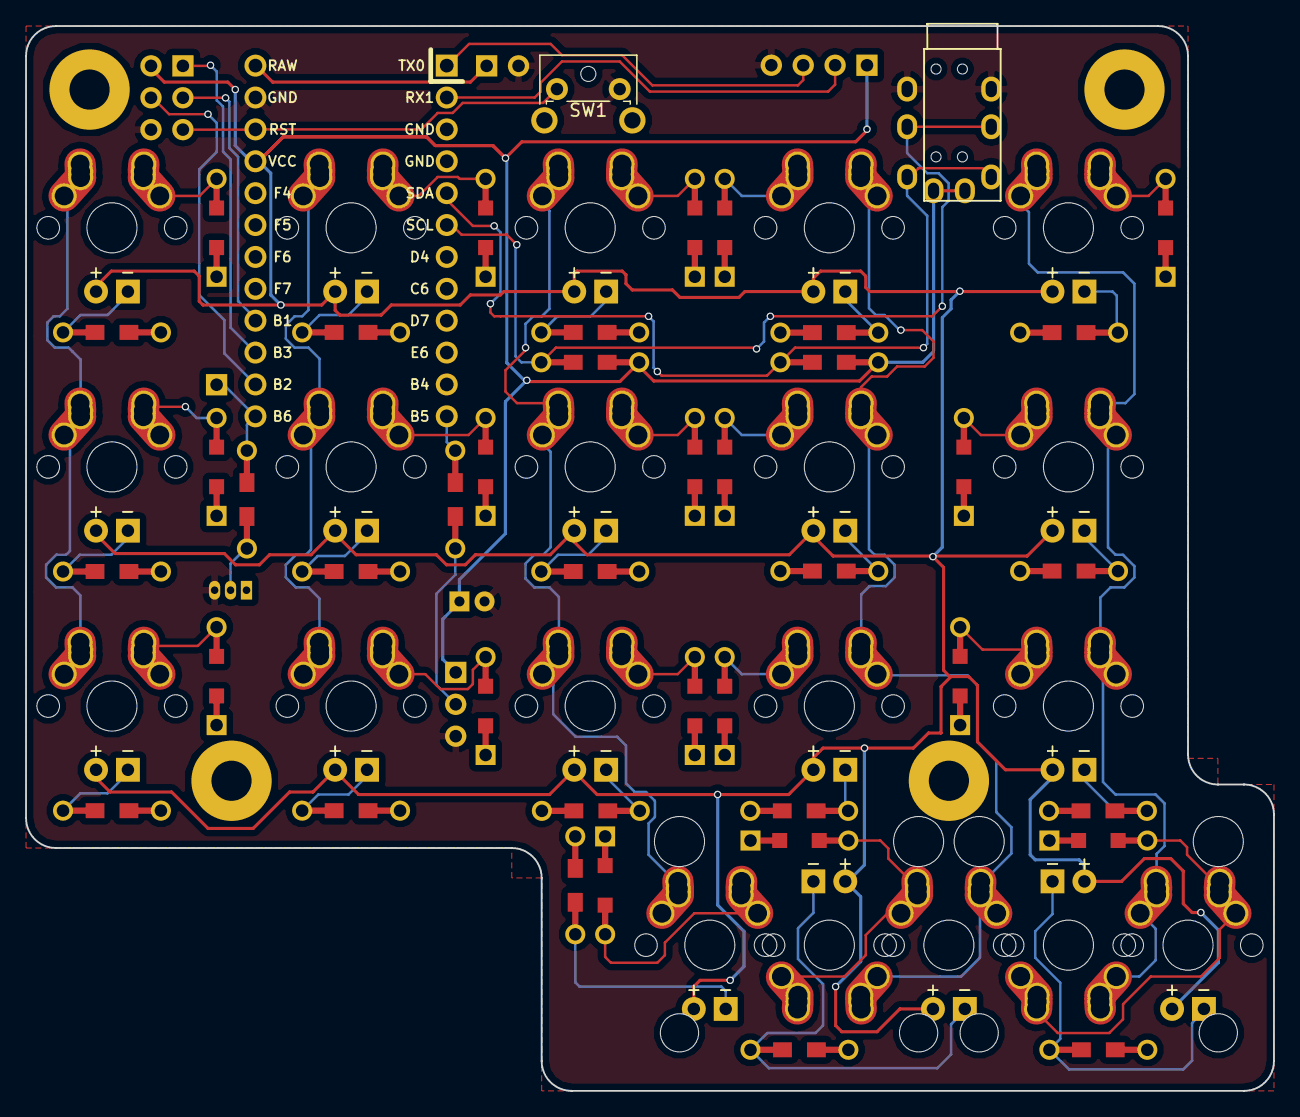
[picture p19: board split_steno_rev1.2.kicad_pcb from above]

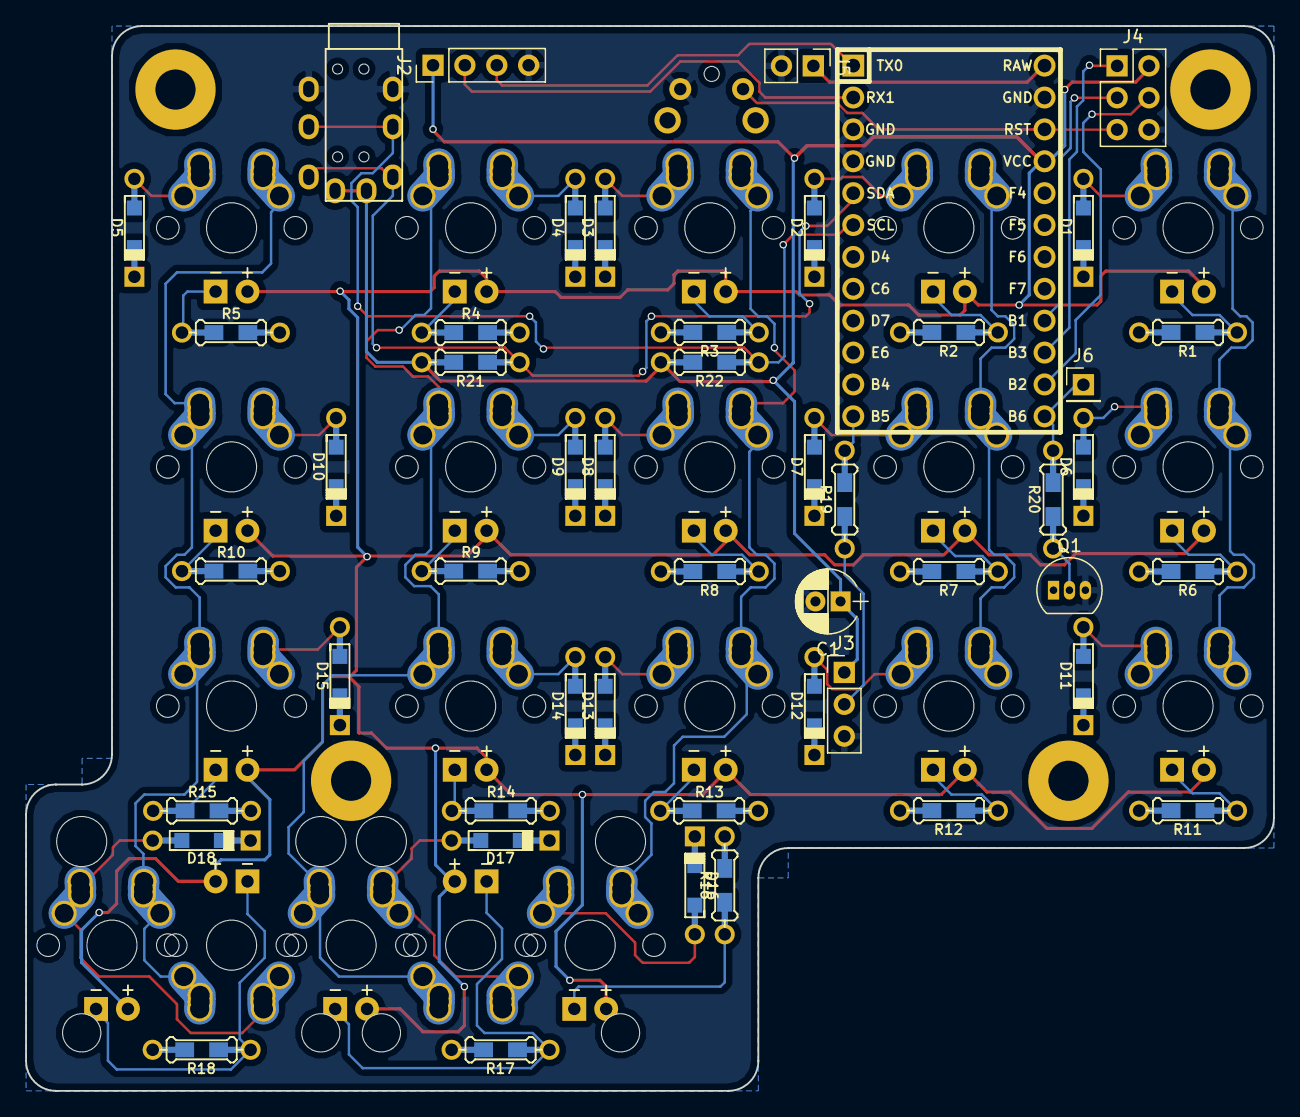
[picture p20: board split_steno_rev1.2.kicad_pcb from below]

Board: 2 copper layers, 99.4 x 84.8 mm, 70 parts (49 on the bottom side), 61 nets.

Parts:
C1: 100; CP_Radial_D5.0mm_P2.00mm
D1, D2, D3, D4, D5, D6, D7, D8, D9, D10, D11, D12, D13, D14, D15, D16, D17, D18: D; Diode-dual
J1: i2c; TRRS-PJ-320A
J2: serial; Pin_Header_Straight_1x04_Pitch2.54mm
J3: rgb; Pin_Header_Straight_1x03_Pitch2.54mm
J4: icsp; Pin_Header_Straight_2x03_Pitch2.54mm
J5: raw; Pin_Header_Straight_1x02_Pitch2.54mm
J6: extra; Pin_Header_Straight_1x01_Pitch2.54mm
MX1, MX2, MX3, MX4, MX5, MX6, MX7, MX8, MX9, MX10, MX11, MX12, MX13, MX14, MX15, MX16, MX18, MX20: MX-1U; Hybrid_PCB_100H_Dual_hole-LED
MX17, MX19: MX-1U; Hybrid_PCB_200H-dual-LED
Q1: BC547; TO-92_Inline_Narrow_Oval
R1, R2, R3, R4, R5, R6, R7, R8, R9, R10, R11, R12, R13, R14, R15, R16, R17, R18: 51; Resistor-Hybrid
R19: 470; Resistor-Hybrid
R20: 1k; Resistor-Hybrid
R21, R22: 4.7k; Resistor-Hybrid
SW1: reset; SW_Tactile_SPST_Angled_MJTP1117
U1: ProMicro; ArduinoProMicro

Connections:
+6V: J5.1, U1.24
/c1: MX1.1, MX6.1, MX11.1, U1.19
/c2: MX2.1, MX7.1, MX12.1, U1.20
/c3: MX3.1, MX8.1, MX13.1, MX16.1, U1.7
/c4: MX4.2, MX9.2, MX14.2, MX17.1, MX18.2, U1.8
/c5: MX5.1, MX10.2, MX15.2, MX19.1, MX20.1, U1.9
/d1: J1.2, R21.1, U1.5
/d2: J1.3, R22.1, U1.6
/d3: R19.2, U1.12
/d4: J6.1, R20.2, U1.13
/miso: J4.1, U1.15
/mosi: J4.4, U1.14
/r1: D1.1, D2.1, D3.1, D4.1, D5.1, U1.18
/r2: D6.1, D7.1, D8.1, D9.1, D10.1, U1.17
/r3: D11.1, D12.1, D13.1, D14.1, D15.1, U1.10
/r4: D16.1, D17.1, D18.1, U1.11
/rst: J4.5, SW1.1, U1.22
/rx: J2.2, U1.2
/sclk: J4.3, U1.16
/tx: J2.3, U1.1
GND: C1.2, J1.4, J2.4, J3.3, J4.6, J5.2, Q1.3, SW1.2, U1.3, U1.4, U1.23
unnamed: D1.2, MX1.2
unnamed: D2.2, MX2.2
unnamed: D3.2, MX3.2
unnamed: D4.2, MX4.1
unnamed: D5.2, MX5.2
unnamed: D6.2, MX6.2
unnamed: D7.2, MX7.2
unnamed: D8.2, MX8.2
unnamed: D9.2, MX9.1
unnamed: D10.2, MX10.1
unnamed: D11.2, MX11.2
unnamed: D12.2, MX12.2
unnamed: D13.2, MX13.2
unnamed: D14.2, MX14.1
unnamed: D15.2, MX15.1
unnamed: D16.2, MX16.2
unnamed: D17.2, MX17.2, MX18.1
unnamed: D18.2, MX19.2, MX20.2
unnamed: J3.2, R19.1
unnamed: MX1.4, R1.1
unnamed: MX2.4, R2.1
unnamed: MX3.4, R3.1
unnamed: MX4.4, R4.1
unnamed: MX5.4, R5.1
unnamed: MX6.4, R6.1
unnamed: MX7.4, R7.1
unnamed: MX8.4, R8.1
unnamed: MX9.4, R9.1
unnamed: MX10.4, R10.1
unnamed: MX11.4, R11.1
unnamed: MX12.4, R12.1
unnamed: MX13.4, R13.1
unnamed: MX14.4, R14.1
unnamed: MX15.4, R15.1
unnamed: MX16.4, R16.1
unnamed: MX17.4, MX18.4, R17.1
unnamed: MX19.4, MX20.4, R18.1
unnamed: Q1.1, R1.2, R2.2, R3.2, R4.2, R5.2, R6.2, R7.2, R8.2, R9.2, R10.2, R11.2, R12.2, R13.2, R14.2, R15.2, R16.2, R17.2, R18.2
unnamed: Q1.2, R20.1
VCC: C1.1, J1.1, J2.1, J3.1, J4.2, MX1.3, MX2.3, MX3.3, MX4.3, MX5.3, MX6.3, MX7.3, MX8.3, MX9.3, MX10.3, MX11.3, MX12.3, MX13.3, MX14.3, MX15.3, MX16.3, MX17.3, MX18.3, MX19.3, MX20.3, R21.2, R22.2, U1.21

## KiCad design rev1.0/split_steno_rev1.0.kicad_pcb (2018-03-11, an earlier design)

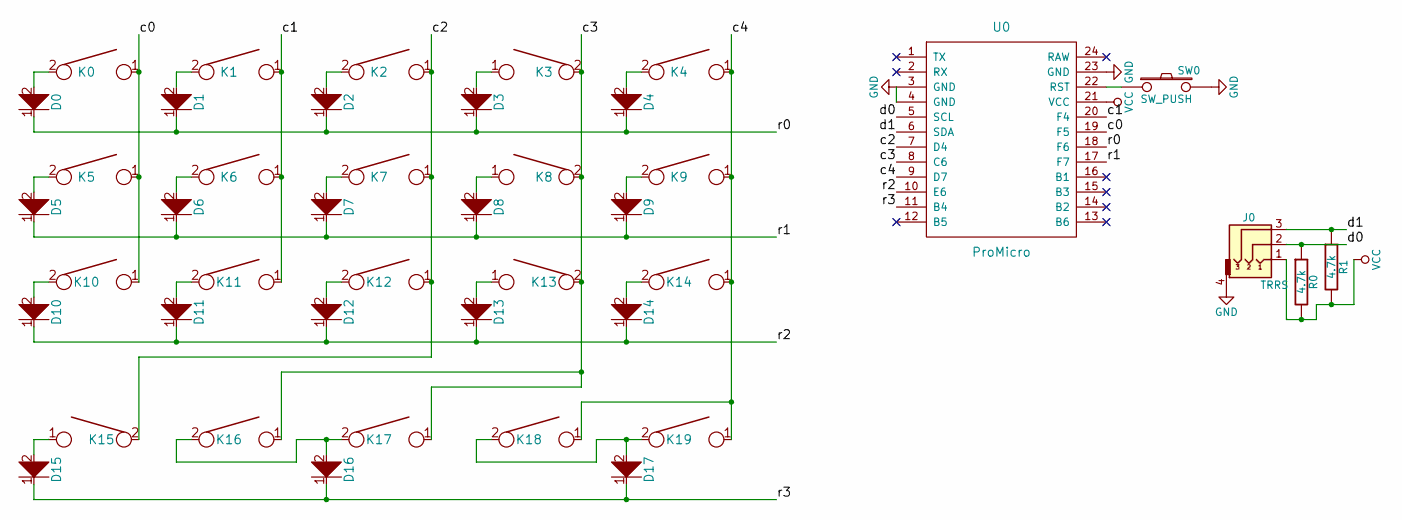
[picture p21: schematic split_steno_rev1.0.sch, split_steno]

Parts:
D0, D1, D2, D3, D4, D5, D6, D7, D8, D9, D10, D11, D12, D13, D14, D15, D16, D17: D; Diode-dual
J0: TRRS; TRRS-PJ-320A
K0, K1, K2, K3, K4, K5, K6, K7, K8, K9, K10, K11, K12, K13, K14, K15, K17, K19: KEYSW; Hybrid_PCB_100H_Dual_hole
K16, K18: KEYSW; Hybrid_PCB_200H-dual-nosilk
R0, R1: 4.7k; Resistor-Hybrid
SW0: SW_PUSH; SW_Tactile_SPST_Angled_MJTP1117
U0: ProMicro; ArduinoProMicro

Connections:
/c0: K0.1, K5.1, K10.1, U0.19 (F5)
/c1: K1.1, K6.1, K11.1, U0.20 (F4)
/c2: K2.1, K7.1, K12.1, K15.2, U0.7 (D4)
/c3: K3.2, K8.2, K13.2, K16.1, K17.1, U0.8 (C6)
/c4: K4.1, K9.1, K14.1, K18.1, K19.1, U0.9 (D7)
/d0: J0.2, R0.1, U0.5 (SCL)
/d1: J0.3, R1.1, U0.6 (SDA)
/r0: D0.1, D1.1, D2.1, D3.1, D4.1, U0.18 (F6)
/r1: D5.1, D6.1, D7.1, D8.1, D9.1, U0.17 (F7)
/r2: D10.1, D11.1, D12.1, D13.1, D14.1, U0.10 (E6)
/r3: D15.1, D16.1, D17.1, U0.11 (B4)
GND: J0.4, SW0.2, U0.3 (GND), U0.4 (GND), U0.23 (GND)
unnamed: D0.2, K0.2
unnamed: D1.2, K1.2
unnamed: D2.2, K2.2
unnamed: D3.2, K3.1
unnamed: D4.2, K4.2
unnamed: D5.2, K5.2
unnamed: D6.2, K6.2
unnamed: D7.2, K7.2
unnamed: D8.2, K8.1
unnamed: D9.2, K9.2
unnamed: D10.2, K10.2
unnamed: D11.2, K11.2
unnamed: D12.2, K12.2
unnamed: D13.2, K13.1
unnamed: D14.2, K14.2
unnamed: D15.2, K15.1
unnamed: D16.2, K16.2, K17.2
unnamed: D17.2, K18.2, K19.2
unnamed: SW0.1, U0.22 (RST)
VCC: J0.1, R0.2, R1.2, U0.21 (VCC)

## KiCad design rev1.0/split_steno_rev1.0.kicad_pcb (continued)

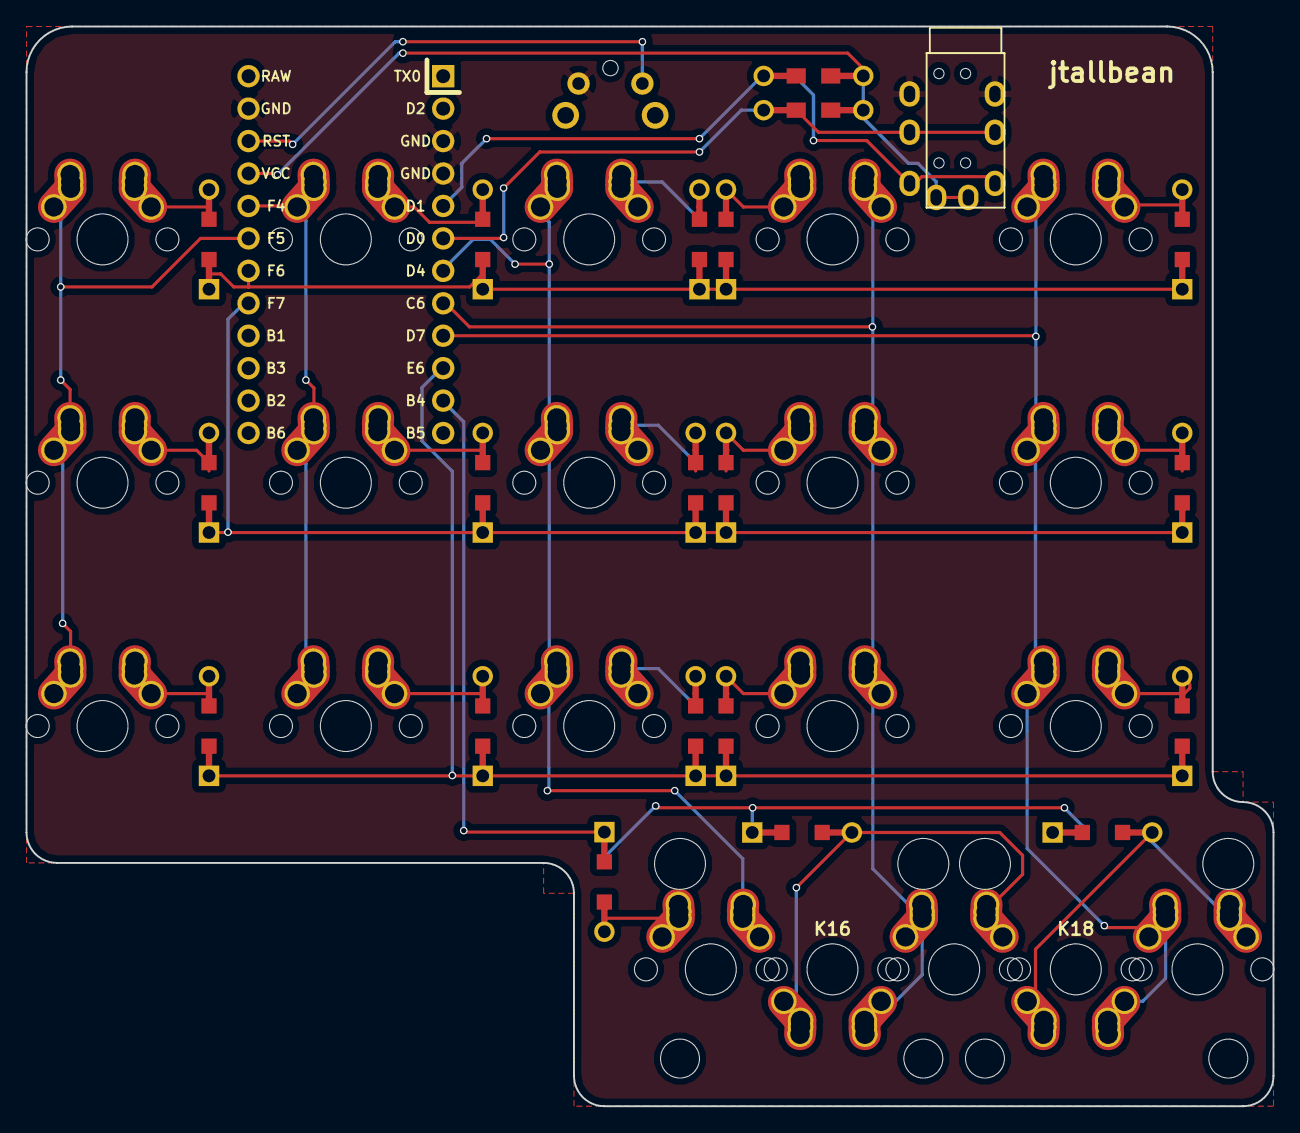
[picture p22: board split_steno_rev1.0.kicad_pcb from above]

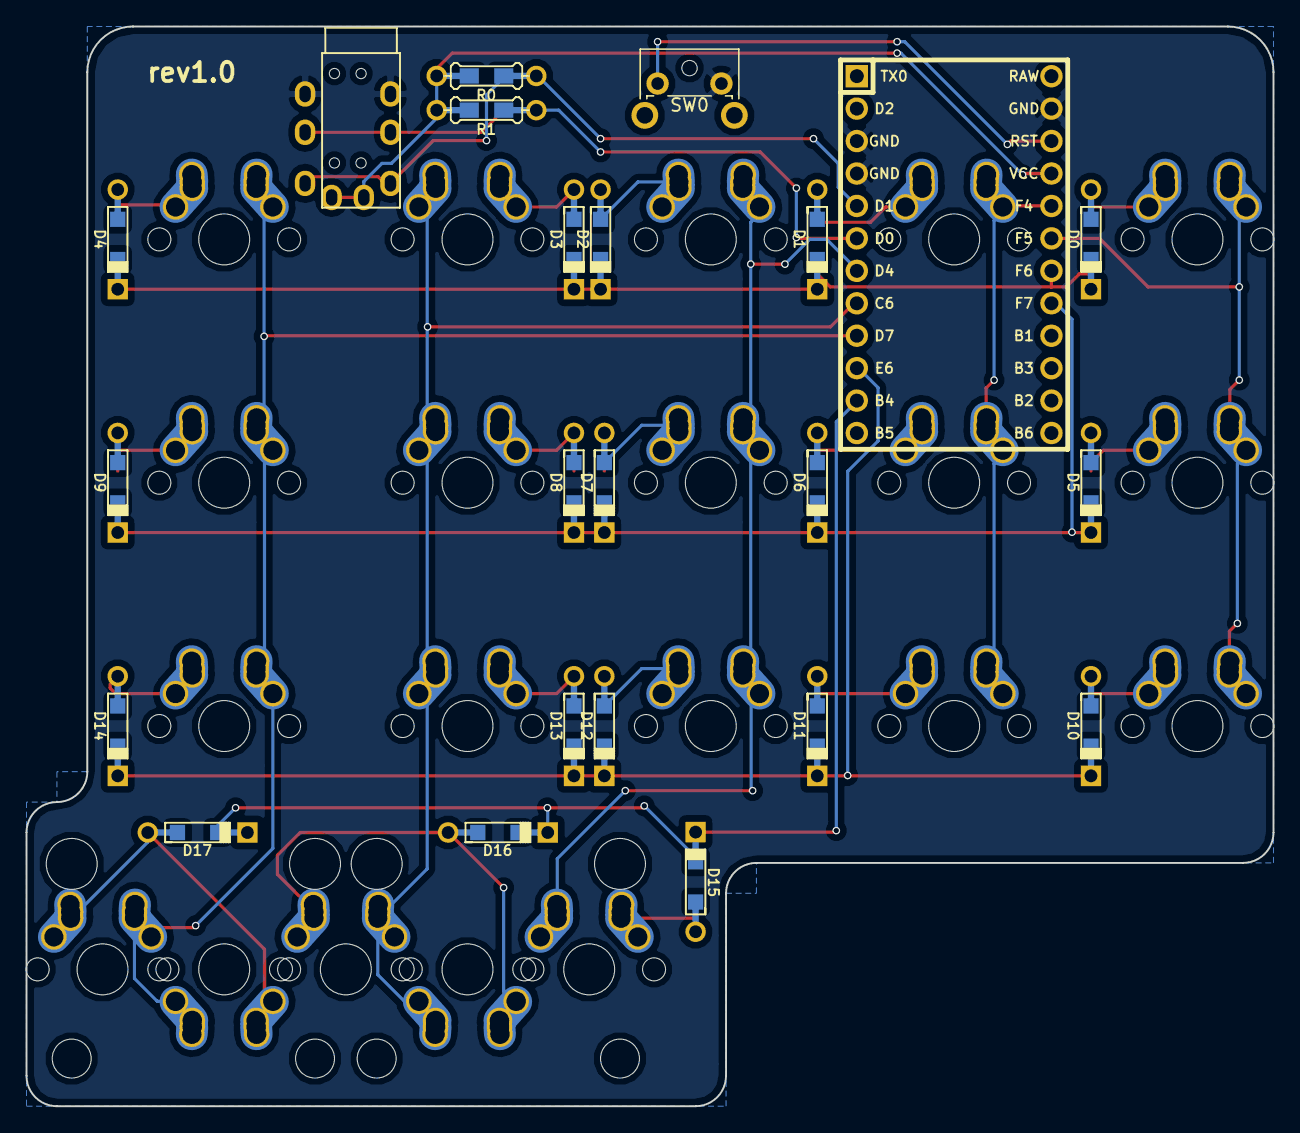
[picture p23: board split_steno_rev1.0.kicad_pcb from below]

Board: 2 copper layers, 97.6 x 84.5 mm, 43 parts (22 on the bottom side), 32 nets.

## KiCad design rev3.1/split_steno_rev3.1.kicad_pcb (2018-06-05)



Board: 2 copper layers, 99.7 x 74.2 mm, 65 parts (39 on the bottom side), 50 nets, no tracks yet.

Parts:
BT1: Battery; CR2032_BK-913
C1, C2, C3, C4, C5, C6, C9, C10, C11, C12: 0.1uF; C_0603_HandSoldering
C8: 1uF; C_0603_HandSoldering
C13: 10uF; C_0603_HandSoldering
C14: 47uF; C_0603_HandSoldering
D1: D_Schottky_x2_KCom_AAK; SOT-23_Handsoldering
F1: Fuse; Fuse_SMD1206_HandSoldering
J1: USB_OTG; USB_miniB_hirose_5S8
J2: Audio-Jack-4; TRRS-PJ-320A
J3: Conn_01x03; Pin_Header_Straight_1x03_Pitch2.54mm
JP1: BAT CHK; Jumper_1x02_P2.54mm_THT
JP2: NO SW; Jumper_1x02_P2.54mm_THT
LED1, LED2, LED3, LED4, LED5, LED6: WS2812B
M2, M2#2, M2#3, M2#4, M2#5, M2#6: MountingHole_2.2mm_M2
P1: TC2030-IDC; TC2030-NL_SMALL_AND_IDC_PDI
R4, R5: 100k; R_0603_HandSoldering
R6: 10k; R_0603_HandSoldering
R7, R8: 4.7k; R_0603_HandSoldering
SW1, SW2, SW3, SW4, SW5, SW6, SW7, SW8, SW9, SW10, SW11, SW12, SW13, SW14, SW15, SW16, SW17, SW18: SW_Push; MX-1U-NoLED
SW19, SW20: SW_Push; MX-2U-NoLED
SW21: SW_Push; SW_Tactile_SPST_Angled_MJTP1117
SW22: Switch-6P-2S2T; SlideSwitch_C&K_JS202011CQN
U1: 74LVC1G34; SOT-23-5_HandSoldering
U4: MCP1700; SOT-23_Handsoldering
U5: ATXMEGA128A4U-AU; TQFP-44_10x10mm_Pitch0.8mm
U6: nRF24L01_module; NRF24L01-Module-SMD

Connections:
+3V3: J2.1, R7.1, R8.1
+5V: C1.1, C2.1, C3.1, C4.1, C5.1, C6.1, F1.2, LED1.1, LED2.1, LED3.1, LED4.1, LED5.1, LED6.1, R4.1, U1.5, U4.3
+BATT: D1.2, JP2.2, SW22.1, SW22.4
/BAT_LVL: JP1.2, U5.32
/CE: U5.13, U6.3
/CSN: U5.14, U6.4
/D+: J1.3, U5.27
/D-: J1.2, U5.26
/IRQ: U5.12, U6.8
/KEY1: SW1.1, U5.25
/KEY2: SW2.1, U5.24
/KEY3: SW3.1, U5.5
/KEY4: SW4.1, U5.4
/KEY5: SW5.1, U5.3
/KEY6: SW6.1, U5.22
/KEY7: SW7.1, U5.23
/KEY8: SW8.1, U5.41
/KEY9: SW9.1, U5.1
/KEY10: SW10.1, U5.2
/KEY11: SW11.1, U5.21
/KEY12: SW12.1, U5.20
/KEY13: SW13.1, U5.40
/KEY14: SW14.1, U5.37
/KEY15: SW15.1, U5.36
/KEY16: SW16.1, U5.42
/KEY17: SW17.1, SW19.1, U5.43
/KEY18: SW18.1, SW20.1, U5.44
/MISO: U5.16, U6.7
/MOSI: U5.15, U6.6
/PDI: P1.1, U5.34
/RST: P1.5, R6.2, SW21.2, U5.35
/SCK: U5.17, U6.5
/SCL: J2.2, R8.2, U5.29
/SDA: J2.3, R7.2, U5.28
/UNDER_LED: U1.2, U5.11
/VBUS_CHECK: R4.2, R5.1, U5.33
GND: BT1.2, C1.2, C2.2, C3.2, C4.2, C5.2, C6.2, C8.2, C9.2, C10.2, C11.2, C12.2, C13.2, C14.2, J1.5, J2.4, LED1.3, LED2.3, LED3.3, LED4.3, LED5.3, LED6.3, P1.6, R5.2, SW1.2, SW2.2, SW3.2, SW4.2, SW5.2, SW6.2, SW7.2, SW8.2, SW9.2, SW10.2, SW11.2, SW12.2, SW13.2, SW14.2, SW15.2, SW16.2, SW17.2, SW18.2, SW19.2, SW20.2, SW21.1, U1.3, U4.1, U5.8, U5.18, U5.30, U5.38, U6.2
unnamed: BT1.1, JP1.1, JP2.1, SW22.2, SW22.5
unnamed: C8.1, D1.1, U4.2
unnamed: F1.1, J1.1
unnamed: J3.1, U5.6
unnamed: J3.2, U5.7
unnamed: J3.3, U5.10
unnamed: LED1.2, LED2.4
unnamed: LED1.4, U1.4
unnamed: LED2.2, LED3.4
unnamed: LED3.2, LED4.4
unnamed: LED4.2, LED5.4
unnamed: LED5.2, LED6.4
VCC: C9.1, C10.1, C11.1, C12.1, C13.1, C14.1, D1.3, P1.2, R6.1, U5.9, U5.19, U5.31, U5.39, U6.1

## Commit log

2018-03-01 move into rev1.0
    [split_steno_rev1.0.kicad_pcb, split_steno_rev1.0.sch]
2018-03-01 added ws2812b
    [split_steno_rev1.0.sch]
2018-03-02 cleaned up schematic
    [split_steno_rev1.0.sch]
2018-03-07 removed LED backlighting
    [split_steno_rev1.0.sch]
2018-03-07 laid out, added gnd plane
    [split_steno_rev1.0.kicad_pcb]
2018-03-07 removed ws2812b, replaced with breakout
    [split_steno_rev1.0.kicad_pcb, split_steno_rev1.0.sch]
2018-03-08 route vcc
    [split_steno_rev1.0.kicad_pcb]
2018-03-08 updated schematic and footprints
    [split_steno_rev1.0.kicad_pcb, split_steno_rev1.0.sch]
2018-03-09 rearranged footprints
    [split_steno_rev1.0.kicad_pcb]
2018-03-10 reorganized files
    [split_steno_rev1.0.sch]
2018-03-11 reorganized schematic library and pro micro footprint
    [_saved_split_steno_rev1.0.sch, split_steno_rev1.0.kicad_pcb, split_steno_rev1.0.sch]
2018-03-11 removed global libraries and moved to local versions
    [_saved_split_steno_rev1.0.sch, split_steno_rev1.0.kicad_pcb, split_steno_rev1.0.sch]
2018-03-11 finished routing traces
    [split_steno_rev1.0.kicad_pcb, split_steno_rev1.0.sch]
2018-03-12 begin rev1.1 - I think I know what I'm doing this time...
    [split_steno_rev1.1.kicad_pcb, split_steno_rev1.1.sch]
2018-03-13 schematic using keyboard_parts library
    [split_steno_rev1.1.sch]
2018-03-13 laid out switch footprints
    [split_steno_rev1.1.kicad_pcb, split_steno_rev1.1.sch]
2018-03-13 laid out led matrix
    [split_steno_rev1.1.kicad_pcb]
2018-03-14 laid out mounting holes
    [split_steno_rev1.1.kicad_pcb]
2018-03-14 routed non-switch traces
    [split_steno_rev1.1.kicad_pcb]
2018-03-15 led/switch routing unfinished - pausing here
    will pause for now - will focus on clean routing and breakouts without leds
    [split_steno_rev1.1.kicad_pcb]
2018-03-15 removed led from rev1.1, moved to rev1.2
    [split_steno_rev1.1.kicad_pcb, split_steno_rev1.1.sch, split_steno_rev1.2.kicad_pcb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]
2018-03-15 finished routing, added silkscreen
    [split_steno_rev1.1.kicad_pcb]
2018-03-16 generated gerbers and library managed
    [split_steno_rev1.1-B.Cu.gbl, split_steno_rev1.1-B.Mask.gbs, split_steno_rev1.1-B.Paste.gbp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]
2018-03-16 one last thing
    [split_steno_rev1.1.kicad_pcb]
2018-03-19 begin rev2.0
    [split_steno_rev2.0.kicad_pcb, split_steno_rev2.0.sch]
2018-03-22 switch and underglow matrix
    [split_steno_rev2.0.sch]
2018-03-26 some updates
    [split_steno_rev2.0.sch]
2018-03-27 switch to diodeless matrix, usb otg
    [split_steno_rev2.0.sch]
2018-03-30 did footprint associations
    [split_steno_rev2.0.sch]
2018-04-01 begin pcb file
    [split_steno_rev2.0.kicad_pcb, split_steno_rev2.0.sch]
2018-04-05 split 2.0 into 2.1
    [split_steno_rev2.1.kicad_pcb, split_steno_rev2.1.sch]
2018-04-05 reduced components, laid out pcb
    [split_steno_rev2.0.kicad_pcb, split_steno_rev2.0.sch]
2018-04-06 laid out pcb
    [split_steno_rev2.1.kicad_pcb, split_steno_rev2.1.sch]
2018-04-07 added 2 more ws2812b
    [split_steno_rev2.1.kicad_pcb, split_steno_rev2.1.sch]
2018-04-07 finished mounting hole placement
    [split_steno_rev2.1.kicad_pcb, split_steno_rev2.1.sch]
2018-04-08 updated some footprints
    [split_steno_rev2.1.kicad_pcb, split_steno_rev2.1.sch]
2018-04-15 redid edge cuts tighter to switches
    [split_steno_rev2.1.kicad_pcb]
2018-04-16 begin working on plate design (cherry+alps with cherry stabilizers)
    [split_steno_plate.dxf, split_steno_rev2.1.kicad_pcb]
2018-04-18 removed lipo charging circuit
    [split_steno_rev2.1.kicad_pcb, split_steno_rev2.1.sch]
2018-04-24 reorganized pins, removed NO USB jumper
    [split_steno_plate_1u_ch.dxf, split_steno_plate_universal_ch_alps.dxf, split_steno_rev2.1.kicad_pcb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]
2018-04-25 laid out components
    [split_steno_rev2.1.kicad_pcb, split_steno_rev2.1.sch]
2018-04-26 routed USB, left side switches
    [split_steno_rev2.1.kicad_pcb, split_steno_rev2.1.sch]
2018-04-27 nrf and usb on both sides of board, rerouted
    [split_steno_rev2.1.kicad_pcb]
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2018-04-28 matched differential pair lengths
    [split_steno_rev2.1.kicad_pcb]
2018-04-30 switched from micro to mini b
    [split_steno_rev2.1.kicad_pcb, split_steno_rev2.1.sch]
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2018-05-09 added mini usb and tag connect to both sides
    [split_steno_rev2.1.kicad_pcb]
2018-05-09 filled in back gnd plane
    [split_steno_rev2.1.kicad_pcb]
2018-05-09 added keepout under nrf module
    [split_steno_rev2.1.kicad_pcb]
2018-05-11 added universal cherry and alps specific plates
    [split_steno_plate_universal_alps.dxf, split_steno_plate_universal_ch.dxf]
2018-05-13 flipped incorrect stabilizer direction
    [split_steno_plate_universal_ch.dxf, split_steno_plate_universal_ch_alps.dxf]
2018-05-18 rev3.0 - remove reversible pcb, dedicated left/right hand
    [split_steno_left.kicad_pcb, split_steno_left.sch]
2018-05-19 added edge cuts, and mounting holes
    [split_steno_left.kicad_pcb, split_steno_left.sch]
2018-05-28 things (i forgot what changed)
    [split_steno_left.kicad_pcb, split_steno_left.sch]
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2018-06-06 starting right hand side
    [split_steno_right.kicad_pcb]
2018-06-06 flipped x values
    [split_steno_right.kicad_pcb, split_steno_right.sch]
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2018-06-11 filled gnd plane on left
    [split_steno_left-B.Cu.gbl, split_steno_left-B.Mask.gbs, split_steno_left-B.Paste.gbp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]
2018-06-12 redid right hand side positions to match left hand
    [split_steno_right.sch]
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
